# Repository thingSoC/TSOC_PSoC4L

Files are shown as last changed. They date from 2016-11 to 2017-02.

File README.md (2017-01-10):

# TSOC_PSoC4L - PSoC4 (Large) Embedded Module :

The TSOC_PSoC4L is a [PSoC4-Programmable System on Chip](http://www.cypress.com/documentation/datasheets/psoc-4-psoc-4200l-family-datasheet)
based board with integrated USB and Li-Po battery power and charging functions, 
in an Embedded Module format for the new thingSoC, Internet of Things open standard.

The TSOC_PSoC4L is a low cost, embeddable module featuring a PSoC4 "Large" device :

* 32-bit MCU Subsystem (48MHZ ARM Cortex-M0)
* USB Full-Speed Controller - 16 Endpoints
* Li-Po battery connector and integrated USB charger
* Programmable Analog Blocks (4 blocks)
* Programmable Digital Blocks (8 blocks)
* 3.3 Volt or 5.0 Volt Operation
* Serial Communication (3 Ports)
* Counter/Timers/PWMs (8 Ports)
* CAN (controller area network) Controller
* Battery Charge Status LED
* USER LED
* USER Pushbutton
* Optional 32Khz Oscillator for Real-Time Clock
* Optional High Precision Oscillator
* Optional FM24W256-G NVSRAM (32K Bytes Nonvolatile SRAM)
* [thingSoC Compliant Module](http://www.thingsoc.com)
* [Mikrobus Compatible Module](http://www.mikroe.com/mikrobus/) 

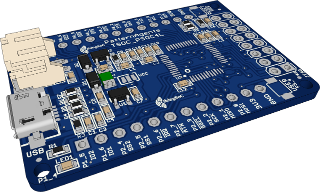
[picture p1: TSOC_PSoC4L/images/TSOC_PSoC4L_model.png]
thingSoC TSOC_PSoC4L
[TSOC_PSoC4L](https://github.com/thingSoC/TSOC_PSoC4L)

**thingSoC Reference Designs** are example thingSoC implementations that implement
various reference and testing circuits for demonstrating the use of the thingSoC libraries.
These reference designs can serve as starting templates for user designs.

---------------------------------------

## TSOC_PSoC4L Instructions

The TSOC_PSoC4L comes preprogrammed with a command line interpreter (CLI)
that runs on the enumerated USB COM port by default. It can be changed to
run onother ports interactively.

Immediately after plugging in the USB or Li-Po battery power the TSOC_PSoC4L will :

1) Runs a USB bootloader for ten (10) seconds to allow you to update the firmware.
   Use the [Cypress Bootloader Host](http://www.cypress.com/documentation/application-notes/an68272-psoc-3-psoc-4-psoc-5lp-and-psoc-analog-coprocessor-uart)
   to load new firmware into the device to customize it.

2) Runs the RSVP command line interpreter with the following commands :
  * commands : display the list of currenyl available commands
  * info : display the firmware revision number and other board details
  * echo : echo the current command
  * test adc : display all current ADC channel values
  * test uart : sends test string to all UART ports
  * test boot : run the bootloader
  * console x : changes the console to port "X"
  * connect x y : connect port x to port y until the user button is pressed to exit  
    where :  X (Y) = 
    0 - USB Port
    1 - UART1 Port
    2 - UART2 Port
    3 - I2C1 Port
    4 - I2C2 Port
    5 - SPI1 Port
    6 - SPI2 Port

---------------------------------------
## Other Applications

The TSOC_PSoC4L can also drive other devices, such as Servos, Motors, Relays and more.
This requires custom firmware at the current time.

---------------------------------------

## TSOC_PSoC4L Status <a name="TSOC_PSoC4L_status"/>

**11/06/2016:** 
Revision 1.0 - Initial Layout released to OSHpark

---------------------------------------
## TSOC_PSoC4L Model Images

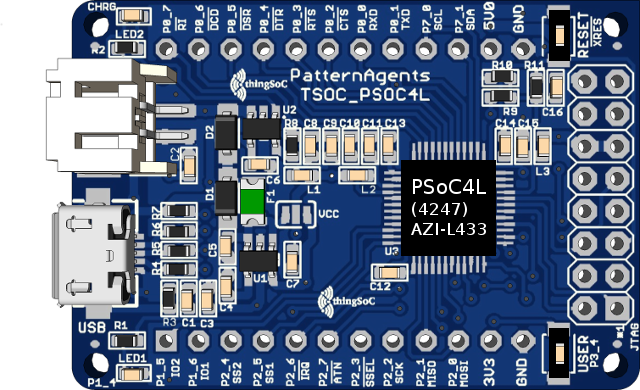
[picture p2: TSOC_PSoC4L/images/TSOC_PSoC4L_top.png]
thingSoC TSOC_PSoC4L
[TSOC_PSoC4L](https://github.com/thingSoC/TSOC_PSoC4L)

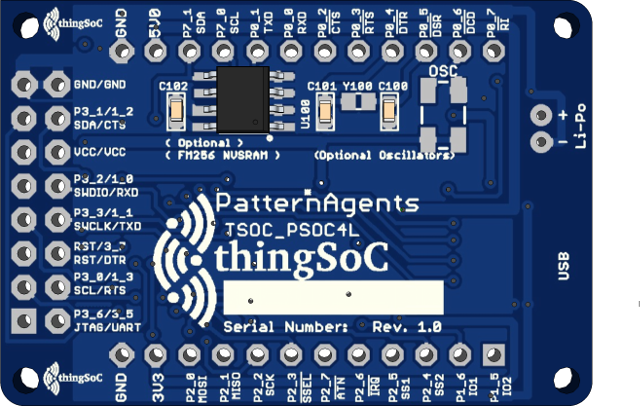
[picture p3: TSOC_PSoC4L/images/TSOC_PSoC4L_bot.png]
thingSoC TSOC_PSoC4L
[TSOC_PSoC4L](https://github.com/thingSoC/TSOC_PSoC4L)

---------------------------------------

## TSOC_PSoC4L Documentation Index <a name="TSOC_PSoC4L_documentation_index"/>

[TSOC_PSoC4L Project](http://thingsoc.github.io/projects/TSOC_PSoC4L.html)

[TSOC_PSoC4L Hardware](https://github.com/thingSoC/TSOC_PSoC4L/tree/master/TSOC_PSoC4L/hardware)

---------------------------------------

## thingSoC Documentation Index <a name="thingSoC_documentation_index"/>

[thingSoC Organization Website](http://thingSoC.github.io)

[thingSoC FAQ - Frequently Asked Questions](http://thingsoc.github.io/support/faq.html)

---------------------------------------

[thingSoC 
*thingSoC*](http://thingsoc.github.io)

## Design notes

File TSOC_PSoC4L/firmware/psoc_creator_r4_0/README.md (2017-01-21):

# TSOC_PSoC4L - PSOC Creator Firmware :

Note Bene : These project firmware bundles require PSOC Creator Version 4.0 or later.

Firmware Source and Images for the TSOC_PSoC4L board.

1) rsvpsis_4l_typ.R1_3_1.zip : First Release bundle.

   USB/HID Bootloader (10 seconds after reset)

   USB/CDC ComX: Interface (after bootloader exits)

   rsvpsis Command Line Interface - basic test functions

   "test" functions UART, ADC, LED, CrossConnect

The TSOC_PSoC4L is a [PSoC4-Programmable System on Chip](http://www.cypress.com/documentation/datasheets/psoc-4-psoc-4200l-family-datasheet)
based board with integrated USB and Li-Po battery power and charging functions, 
in an Embedded Module format for the new thingSoC, Internet of Things open standard.

---------------------------------------

## TSOC_PSoC4L Documentation Index <a name="TSOC_PSoC4L_documentation_index"/>

[TSOC_PSoC4L Project](http://thingsoc.github.io/projects/TSOC_PSoC4L.html)

[TSOC_PSoC4L Hardware](https://github.com/thingSoC/TSOC_PSoC4L/tree/master/TSOC_PSoC4L/hardware)

---------------------------------------

## thingSoC Documentation Index <a name="thingSoC_documentation_index"/>

[thingSoC Organization Website](http://thingSoC.github.io)

[thingSoC FAQ - Frequently Asked Questions](http://thingsoc.github.io/support/faq.html)

---------------------------------------

[thingSoC 
*thingSoC*](http://thingsoc.github.io)

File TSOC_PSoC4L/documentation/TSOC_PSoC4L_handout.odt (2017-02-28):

thingSoC PSoC4L Board

Thank you for purchasing a TSOC_PSoC4L board!
Please see the Getting Started Guide at :
https://github.com/thingSoC/TSOC_PSoC4L (https://github.com/thingSoC/TSOC_NEOLED)
It has complete instructions and examples to download.

thingSoC PSoC4L Board

Thank you for purchasing a TSOC_PSoC4L board!
Please see the Getting Started Guide at :
https://github.com/thingSoC/TSOC_PSoC4L (https://github.com/thingSoC/TSOC_NEOLED)
It has complete instructions and examples to download.

thingSoC PSoC4L Board

Thank you for purchasing a TSOC_PSoC4L board!
Please see the Getting Started Guide at :
https://github.com/thingSoC/TSOC_PSoC4L (https://github.com/thingSoC/TSOC_NEOLED)
It has complete instructions and examples to download.

thingSoC PSoC4L Board

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

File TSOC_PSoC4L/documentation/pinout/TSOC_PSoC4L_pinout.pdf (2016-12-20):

Sheet1

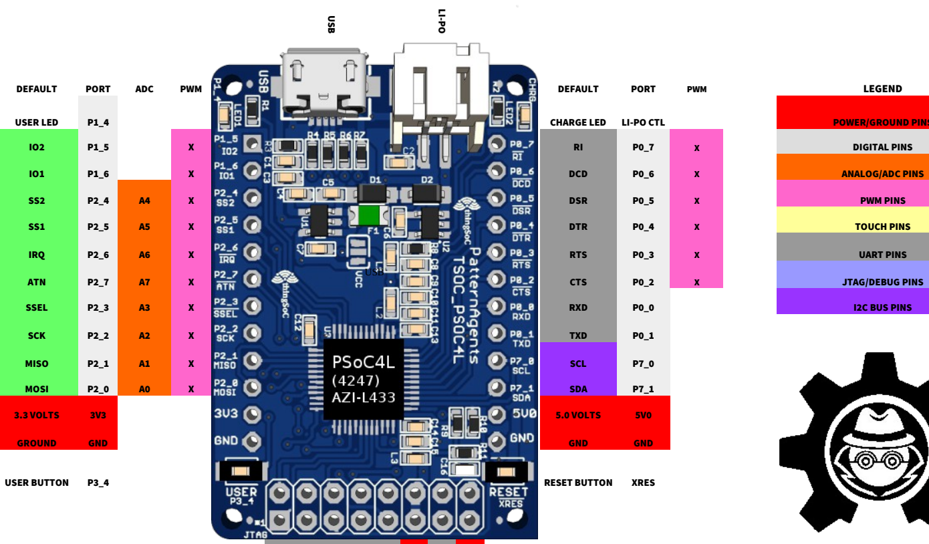
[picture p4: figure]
USB; DIGITAL PINS; DCD; ANALOG/ADC PINS; DSR; PWM PINS; DTR; TOUCH PINS; IRQ; RTS; UART PINS; SSEL; RXD; I2C BUS PINS; SCK; TXD; MISO; SCL; MOSI; SDA; 3.3 VOLTS; 5.0 VOLTS; GROUND; GND; USER BUTTON; RESET BUTTON; XRES

Page 1

DEFAULT | PORT | ADC | PWM | DEFAULT | PORT | PWM | LEGEND
USER LED | P1_4 | | | CHARGE LED | LI-PO CTL | | POWER/GROUND PINS
ATN | P2_7 | A7 | X | CTS | P0_2 | X | JTAG/DEBUG PINS

DSR1 (P3_5)
RTS1 (P1_3)

DTR1 (P3_7)
TXD1 (P1_1)

RXD1 (P1_0)

5V0

CTS1 (P1_2)

GND

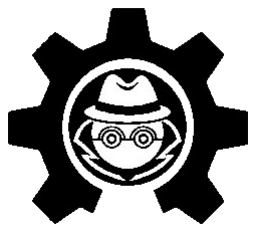
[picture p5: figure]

## PatternAgents TSOC_PSoC4L Board

DEBUG (P3_6)
SCL1 (P3_0)
RESET#

SWDCLK (P3_3)
SWDIO (P3_2)

VCC

SDA1 (P3_1)

GND

## thingsoc/TSOC_PSoC4L/ (http://github.com/thingsoc/TSOC_PSoC4L/)

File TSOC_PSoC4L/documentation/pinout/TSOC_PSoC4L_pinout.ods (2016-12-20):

 |  |  |  |  |  | USB |  |  |  | LI-PO
DEFAULT | PORT | ADC | PWM |  |  |  |  |  |  |  |  | DEFAULT | PORT | PWM | LEGEND
USER LED | P1_4 |  |  |  |  |  |  |  |  |  |  | CHARGE LED | LI-PO CTL |  | POWER/GROUND PINS
IO2 | P1_5 |  | X |  |  |  |  |  |  |  |  | RI | P0_7 | X | DIGITAL PINS
IO1 | P1_6 |  | X |  |  |  |  |  |  |  |  | DCD | P0_6 | X | ANALOG/ADC PINS
SS2 | P2_4 | A4 | X |  |  |  |  |  |  |  |  | DSR | P0_5 | X | PWM PINS
SS1 | P2_5 | A5 | X |  |  |  |  |  |  |  |  | DTR | P0_4 | X | TOUCH PINS
IRQ | P2_6 | A6 | X |  |  |  |  |  |  |  |  | RTS | P0_3 | X | UART PINS
ATN | P2_7 | A7 | X |  |  |  |  |  |  |  |  | CTS | P0_2 | X | JTAG/DEBUG PINS
SSEL | P2_3 | A3 | X |  |  |  |  |  |  |  |  | RXD | P0_0 |  | I2C BUS PINS
SCK | P2_2 | A2 | X |  |  |  |  |  |  |  |  | TXD | P0_1 |  | SPI BUS PINS
MISO | P2_1 | A1 | X |  |  |  |  |  |  |  |  | SCL | P7_0
MOSI | P2_0 | A0 | X |  |  |  |  |  |  |  |  | SDA | P7_1
3.3 VOLTS | 3V3 |  |  |  |  |  |  |  |  |  |  | 5.0 VOLTS | 5V0
GROUND | GND |  |  |  |  |  |  |  |  |  |  | GND | GND
USER BUTTON | P3_4 |  |  |  |  |  |  |  |  |  |  | RESET BUTTON | XRES
 |  |  |  | DSR1 (P3_5) | RTS1 (P1_3) | DTR1 (P3_7) | TXD1 (P1_1) | RXD1 (P1_0) | 5V0 | CTS1 (P1_2) | GND |  |  | PatternAgents TSOC_PSoC4L Board
 |  |  |  | DEBUG (P3_6) | SCL1 (P3_0) | RESET# | SWDCLK (P3_3) | SWDIO (P3_2) | VCC | SDA1 (P3_1) | GND |  | thingsoc/TSOC_PSoC4L/ (http://github.com/thingsoc/TSOC_PSoC4L/)

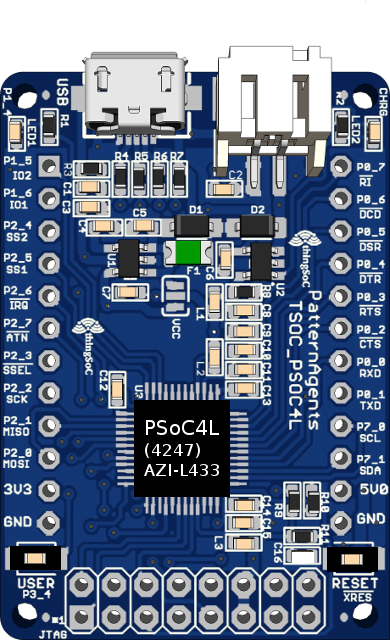
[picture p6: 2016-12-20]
TSOC_PSoC4L/images/TSOC_PSoC4L_pinout.png

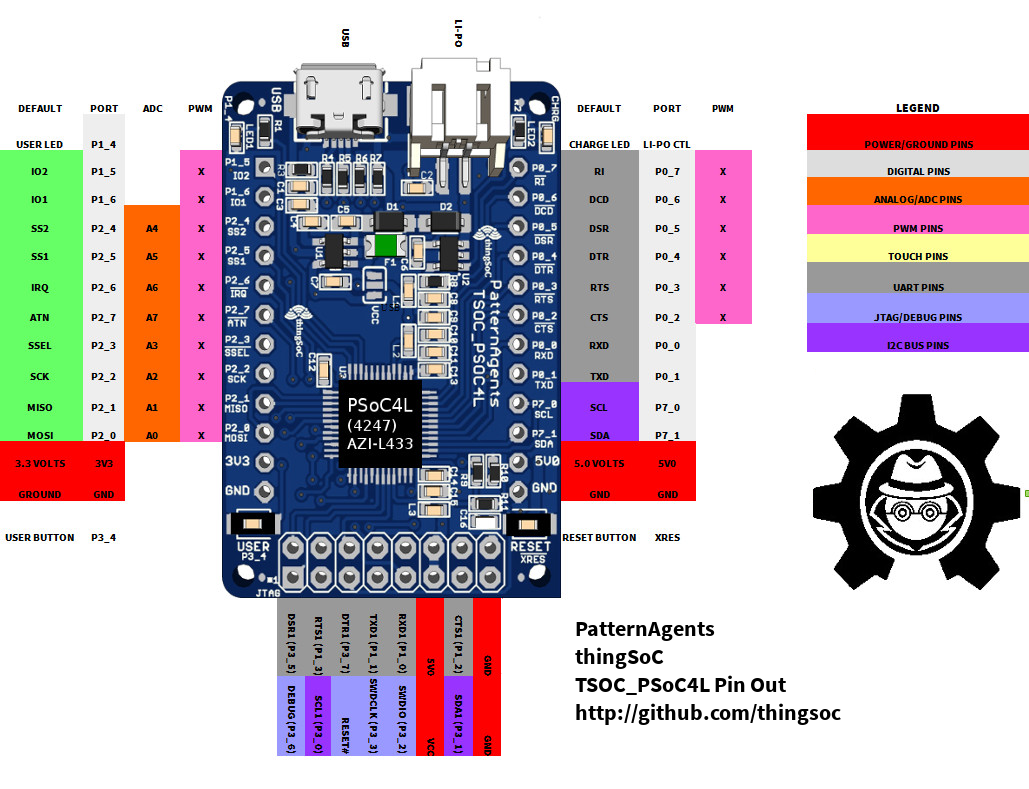
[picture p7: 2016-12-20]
TSOC_PSoC4L/documentation/pinout/TSOC_PSoC4L_pinout.png

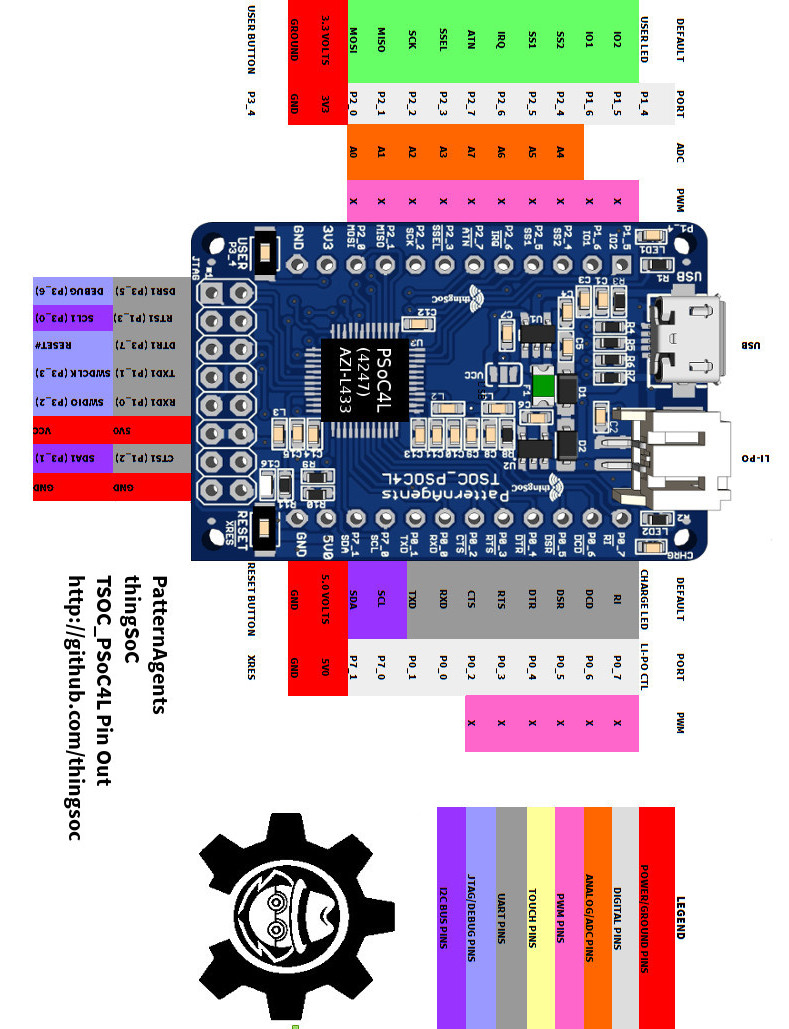
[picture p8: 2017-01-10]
TSOC_PSoC4L/documentation/pinout/TSOC_PSoC4L_pinout_long.jpg

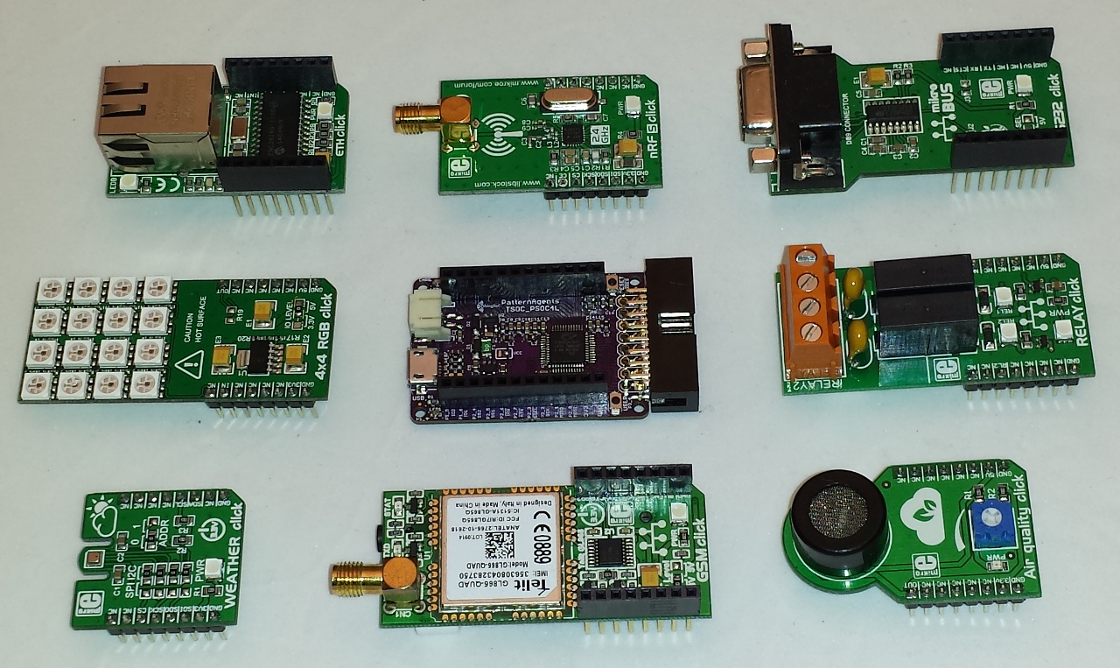
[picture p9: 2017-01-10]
TSOC_PSoC4L/images/product/TSOC_PSoC4L_Clicks.jpg

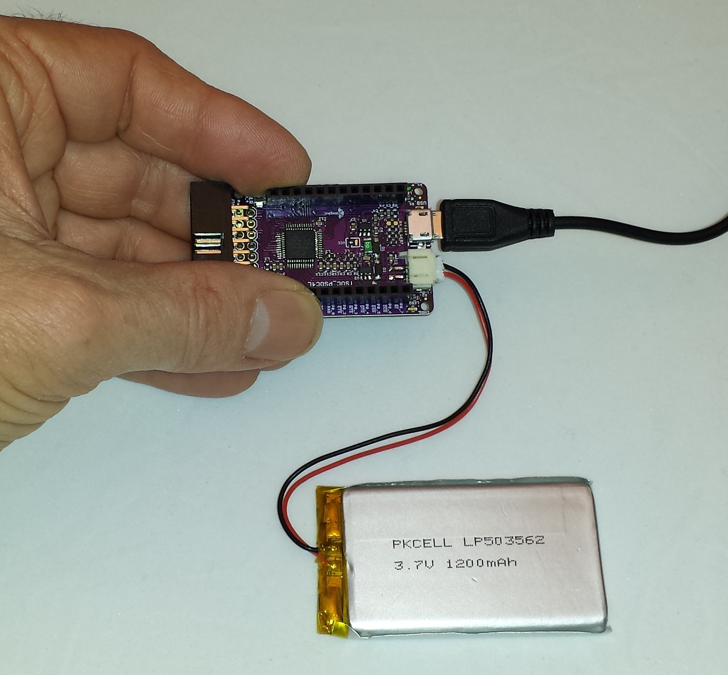
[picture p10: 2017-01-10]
TSOC_PSoC4L/images/product/TSOC_PSoC4L_USB_LiPo.jpg

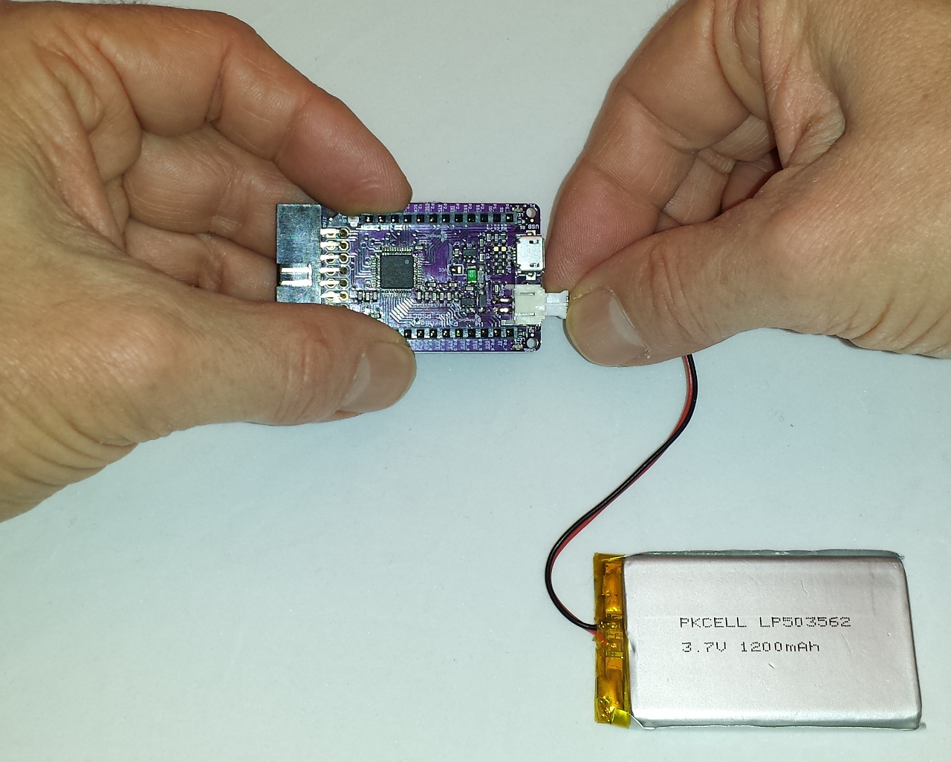
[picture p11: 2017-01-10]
TSOC_PSoC4L/images/product/TSOC_PSoC4L_LiPo1.jpg

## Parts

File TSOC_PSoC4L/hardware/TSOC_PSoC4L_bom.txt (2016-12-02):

Partlist exported from U:/PatternAgents/eagle/TSOC_Modules/TSOC_PSoC4L/TSOC_PSoC4L/revisions/REV1_0/TSOC_PSoC4L.sch at 11/17/2016 4:03:40 PM

Qty Value             Device                                                Package                   Parts                           Description                                                                                                   
1                     JST_2MM_MALE                                          JST-2-SMD                 BATTERY                         Mates to single-cell LiPo batteries.                                                                          
1                     M02-JST-2-PTH-NO_SILK                                 JST-2-PTH-NS              J1P                             Standard 2-pin 0.1" header. Use with                                                                          
1                     M08X2                                                 2X8                       JTAG                            .1" headers, two rows of 8 each                                                                               
7   100nf             CERAMIC-100NF-50V-10%-X7R(0603)                       C0603                     C1, C4, C8, C11, C14, C16, C102 302010138                                                                                                     
4   10K 1/10W         SMD-RES-10K-5%-1/10W(0603)                            R0603                     R8, R9, R10, R11                301010293                                                                                                     
3   10uf              CERAMIC-10UF-10V-10%-X5R(0603)                        C0603                     C3, C5, C7                      302010103                                                                                                     
2   12pf              CERAMIC-12PF-50V-5%-NPO(0603)                         C0603                     C100, C101                      302010067                                                                                                     
2   1K 1/10W          SMD-RES-1K-5%-1/10W(0603)                             R0603                     R1, R2                          301010291 
2   0 1/10W           SMD-RES-0-5%-1/10W(0603)                              R0603                     R7 
1   1M 1/10W          SMD-RES-1M-5%-1/10W(0603)                             R0603                     R3                              301010100                                                                                                     
7   1uf               CERAMIC-1UF-25V-10%-X7R(0603)                         C0603                     C2, C6, C9, C10, C12, C13, C15  302010139                                                                                                     
2   20V-1A            SMD-DIODE-SCHOTTKY-20V-1A(SOD-123)                    SOD-123                   D1, D2                          304020034                                                                                                     
2   22R               SMD-RES-22R-5%-1/10W(0603)                            R0603                     R5, R6                          301010289                                                                                                     
1   3.2768KHZ         SMD-CRYSTAL-32.768KHZ-12.5PF-20PPM-90K(2P-L2.0X1.2MM) X2-SMD-L2.0X1.2X0.55MM    Y100                            306010020                                                                                                     
3   330OHM-500MA      SMD-FERRITE-CHIP-120-OHM-500MA(0603)                  L0603                     L1, L2, L3                      303030001                                                                                                     
1   500mA-PTC         PTCSMD                                                PTC-1206                  F1                              Resettable Fuse PTC                                                                                           
1   AP2112K-3.3V      V_REG_LDOSMD                                          SOT23-5                   U1                              Voltage Regulator LDO                                                                                         
2   B3U-1000P-2P-SMD  SMD-BUTTON(2P-3.0X2.5X1.2+0.4MM)-B3U-1000P-2P-SMD     SW2-2.6-3.0X2.5X1.2+0.4MM RESET, USER                     311020047                                                                                                     
1   CY8C4247AZI-L433  CY8C4247AZI-L433                                      TQFP-7X7-48               U3                              Cypress PSoC® 4 - Programmable System on Chip,  Cortex-M0 Based : USB Version!                                
1   DNP               SMD-RES-22R-5%-1/10W(0603)                            R0603                     R4                              301010289                                                                                                     
4   FIDUCIALUFIDUCIAL FIDUCIALUFIDUCIAL                                     MICRO-FIDUCIAL            FID1, FID2, FID3, FID4          Fiducial Alignment Points                                                                                     
1   FM24W256-G        FM24W256-G                                            SO08                      U100                            I2C FRAM FM24W256                                                                                             
1   GREEN-0603        SMD-LED-CLEAR-GREEN(0603)                             LED-0603                  LED1                            304090043                                                                                                     
1   JMP-3-1_2         JMP-3-1_2                                             JMP-3-1_2                 VCC                             Three Terminal Jumper - 1 & 2 Connected                                                                       
1   MCP73831          MCP73831                                              SOT23-5                   U2                              Miniature single cell, fully integrated Li-Ion, Li-polymer charge management controller                       
1   OSCILLATOR5X3     OSCILLATOR5X3                                         CRYSTAL-SMD-5X3           OSC                             Generic 5x3 and 7x5 oscillators                                                                               
1   USB_AB            USB_AB                                                USB-AB-MICRO-SMD          USB                             This is a USB AB connector that is compatible with USB OTG. i.e. this connector can serve as a host or device 
1   YELLOW-0603       SMD-LED-CLEAR-YELLOW(0603)                            LED-0603                  LED2                            304090044

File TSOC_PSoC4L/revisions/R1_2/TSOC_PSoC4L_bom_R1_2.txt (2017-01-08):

Partlist exported from U:/PatternAgents/eagle/TSOC_Modules/TSOC_PSoC4L/TSOC_PSoC4L/revisions/R1_2/TSOC_PSoC4L.sch at 12/18/2016 4:06:15 PM

Qty Value             Device                               Package           Parts                                 Description                                                                                                   
1   AP2112K-3.3V      V_REG_LDOSMD                         SOT23-5           U1                                    Voltage Regulator LDO                                                                                         
1   MCP73831          MCP73831                             SOT23-5           U2                                    Miniature single cell                     
1   CY8C4247AZI-L433  CY8C4247AZI-L433                     TQFP-7X7-48       U3                                    Cypress PSoC® 4 -                         
8   100nf             CERAMIC-100NF-50V-10%-X7R(0603)      C0603             C1, C8, C11, C14, C16, C102, C103     302010138                                                                                                     
3   10uf              CERAMIC-10UF-10V-10%-X5R(0603)       C0603             C3, C5, C7                            302010103                                                                                                     
7   1uf               CERAMIC-1UF-25V-10%-X7R(0603)        C0603             C2, C6, C9, C10, C12, C13, C15        302010139                                                                                                     
1   47uf              TANTALUM-SMD-47UF-6.3V(AVX-A)        AVX-A             C17                                   302020005                                                                                                     
2   1K 1/10W          SMD-RES-1K-5%-1/10W(0603)            R0603             R1, R2                                301010291                                                                                                     
1   1M 1/10W          SMD-RES-1M-5%-1/10W(0603)            R0603             R3                                    301010100                                                                                                     
2   22R               SMD-RES-22R-5%-1/10W(0603)           R0603             R5, R6                                301010289
4   10K 1/10W         SMD-RES-1M-5%-1/10W(0603)            R0603             R8, R9, R10, R11                                                                                               
3   330OHM-500MA      SMD-FERRITE-CHIP-120-OHM-500MA(0603) L0603             L1, L2, L3                            303030001                                                                                                     
2   20V-1A            SMD-DIODE-SCHOTTKY-20V-1A(SOD-123)   SOD-123           D1, D2                                304020034                                                                                                     
1   500mA-PTC         PTCSMD                               PTC-1206          F1                                    Resettable Fuse PTC                                                                                           
2   B3U-1000P-2P-SMD  SMD-BUTTON(2P-3.0X2.5X1.2+0.4MM      SW2               RESET, USER                           311020047                                                                                                     
1   GREEN-0603        SMD-LED-CLEAR-GREEN(0603)            LED-0603          LED1                                  304090043                                                                                                     
1   YELLOW-0603       SMD-LED-CLEAR-YELLOW(0603)           LED-0603          LED2                                  304090044                                                                                                     
1   JMP-3-1_2         JMP-3-1_2                            JMP-3-1_2         VCC                                   Three Terminal Jumper - 1 & 2 Connected                                                                       
1   USB_AB            USB_AB                               USB-AB-MICRO-SMD  USB                                   This is a USB AB 
1                     JST_2MM_MALE                         JST-2-SMD         BATTERY                               Mates to single-c                                                                        
1                     M02-JST-2-PTH-NO_SILK                JST-2-PTH-NS      J1P                                   Standard 2-pin                                                                        
1                     M08X2                                2X8               JTAG                                  .1" headers, two rows of 8 each                                                                               

Do Not Populate!
----------------
1   DNP               470pf                                C0603             C4
1   DNP               SMD-RES-22R-5%-1/10W(0603)           R0603             R4                                                                                                                                         
1   FM24W256-G        FM24W256-G                           SO08              U100                                  I2C FRAM FM24W256                                                                                             
2   12pf              CERAMIC-12PF-50V-5%-NPO(0603)        C0603             C100, C101                            302010067                                                                                                     
1   3.2768KHZ         SMD-CRYSTAL-32.768KHZ-12.5PF-20PPM   X2-SMD            Y100                                  306010020                                                                                                     
1   OSCILLATOR5X3     OSCILLATOR5X3                        CRYSTAL-SMD-5X3   Y101                                  Generic 5x3 and 7x5 oscillators

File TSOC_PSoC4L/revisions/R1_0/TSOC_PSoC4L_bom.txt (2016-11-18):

Partlist exported from U:/PatternAgents/eagle/TSOC_Modules/TSOC_PSoC4L/TSOC_PSoC4L/revisions/REV1_0/TSOC_PSoC4L.sch at 11/17/2016 4:03:40 PM

Qty Value             Device                                                Package                   Parts                           Description                                                                                                   
1                     JST_2MM_MALE                                          JST-2-SMD                 BATTERY                         Mates to single-cell LiPo batteries.                                                                          
1                     M02-JST-2-PTH-NO_SILK                                 JST-2-PTH-NS              J1P                             Standard 2-pin 0.1" header. Use with                                                                          
1                     M08X2                                                 2X8                       JTAG                            .1" headers, two rows of 8 each                                                                               
7   100nf             CERAMIC-100NF-50V-10%-X7R(0603)                       C0603                     C1, C4, C8, C11, C14, C16, C102 302010138                                                                                                     
4   10K 1/10W         SMD-RES-10K-5%-1/10W(0603)                            R0603                     R8, R9, R10, R11                301010293                                                                                                     
3   10uf              CERAMIC-10UF-10V-10%-X5R(0603)                        C0603                     C3, C5, C7                      302010103                                                                                                     
2   12pf              CERAMIC-12PF-50V-5%-NPO(0603)                         C0603                     C100, C101                      302010067                                                                                                     
3   1K 1/10W          SMD-RES-1K-5%-1/10W(0603)                             R0603                     R1, R2, R7                      301010291                                                                                                     
1   1M 1/10W          SMD-RES-1M-5%-1/10W(0603)                             R0603                     R3                              301010100                                                                                                     
7   1uf               CERAMIC-1UF-25V-10%-X7R(0603)                         C0603                     C2, C6, C9, C10, C12, C13, C15  302010139                                                                                                     
2   20V-1A            SMD-DIODE-SCHOTTKY-20V-1A(SOD-123)                    SOD-123                   D1, D2                          304020034                                                                                                     
2   22R               SMD-RES-22R-5%-1/10W(0603)                            R0603                     R5, R6                          301010289                                                                                                     
1   3.2768KHZ         SMD-CRYSTAL-32.768KHZ-12.5PF-20PPM-90K(2P-L2.0X1.2MM) X2-SMD-L2.0X1.2X0.55MM    Y100                            306010020                                                                                                     
3   330OHM-500MA      SMD-FERRITE-CHIP-120-OHM-500MA(0603)                  L0603                     L1, L2, L3                      303030001                                                                                                     
1   500mA-PTC         PTCSMD                                                PTC-1206                  F1                              Resettable Fuse PTC                                                                                           
1   AP2112K-3.3V      V_REG_LDOSMD                                          SOT23-5                   U1                              Voltage Regulator LDO                                                                                         
2   B3U-1000P-2P-SMD  SMD-BUTTON(2P-3.0X2.5X1.2+0.4MM)-B3U-1000P-2P-SMD     SW2-2.6-3.0X2.5X1.2+0.4MM RESET, USER                     311020047                                                                                                     
1   CY8C4247AZI-L433  CY8C4247AZI-L433                                      TQFP-7X7-48               U3                              Cypress PSoC® 4 - Programmable System on Chip,  Cortex-M0 Based : USB Version!                                
1   DNP               SMD-RES-22R-5%-1/10W(0603)                            R0603                     R4                              301010289                                                                                                     
4   FIDUCIALUFIDUCIAL FIDUCIALUFIDUCIAL                                     MICRO-FIDUCIAL            FID1, FID2, FID3, FID4          Fiducial Alignment Points                                                                                     
1   FM24W256-G        FM24W256-G                                            SO08                      U100                            I2C FRAM FM24W256                                                                                             
1   GREEN-0603        SMD-LED-CLEAR-GREEN(0603)                             LED-0603                  LED1                            304090043                                                                                                     
1   JMP-3-1_2         JMP-3-1_2                                             JMP-3-1_2                 VCC                             Three Terminal Jumper - 1 & 2 Connected                                                                       
1   MCP73831          MCP73831                                              SOT23-5                   U2                              Miniature single cell, fully integrated Li-Ion, Li-polymer charge management controller                       
1   OSCILLATOR5X3     OSCILLATOR5X3                                         CRYSTAL-SMD-5X3           OSC                             Generic 5x3 and 7x5 oscillators                                                                               
1   TSOC-24-BB        TSOC-24-BB                                            TSOC-BB-S24               A                               thingSoC Twenty-Four(24) Pin Socket                                                                           
1   TSOC-LOGO-LRG     TSOC-LOGO-LRG                                         TSOC-LOGO-LRG             U$100                           thingSoC Logo                                                                                                 
3   TSOC-LOGO-SMALL   TSOC-LOGO-SMALL                                       TSOC-LOGO-SML             $$U$1, $$U$2, U$101             thingSoC Logo                                                                                                 
1   TSOC-PCB-SINGLE   TSOC-PCB-SINGLE                                       TSOC-BB-BRD-DIM           U$1                             thingSoC PCB Outlines                                                                                         
1   USB_AB            USB_AB                                                USB-AB-MICRO-SMD          USB                             This is a USB AB connector that is compatible with USB OTG. i.e. this connector can serve as a host or device 
1   YELLOW-0603       SMD-LED-CLEAR-YELLOW(0603)                            LED-0603                  LED2                            304090044

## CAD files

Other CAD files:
TSOC_PSoC4L/eagleUp/TSOC_PSoC4L.skp

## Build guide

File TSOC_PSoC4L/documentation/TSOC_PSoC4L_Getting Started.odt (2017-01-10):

Welcome to the thingSoC® PsoC4L (Large)

The TSOC_PSoC4L is a PSoC4-Programmable System on Chip (http://www.cypress.com/documentation/datasheets/psoc-4-psoc-4200l-family-datasheet) based board with integrated USB ,
Li-Po battery power and charging functions, in an Embedded Module format for the new thingSoC, Internet of Things open source hardware standard.

Getting Started :

1) Using a USB-Micro cable, plug the PSoC4L board into your Windows, MAC, or Linux PC.

2) The USB drivers should be found automatically on most systems.
However if they are not, they can be downloaded from :
https://github.com/thingSoC/TSOC_PSoC4L/tree/master/TSOC_PSoC4L/drivers

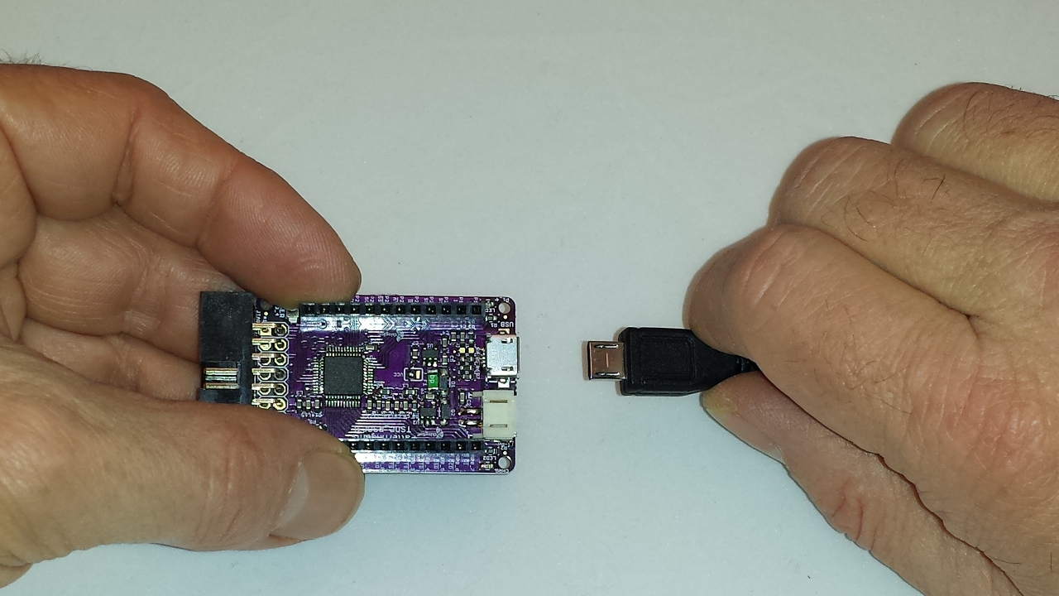
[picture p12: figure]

3) With the default firmware, when the PSoC4L board is first connected to power,
it will run the USB Bootloader program for the first ten (10) seconds of operation.
If a bootloader request to update the internal formware is not received within ten (10) seconds,
then the PSoC4L board will enter it's normal operating mode. In bootloader mode the PSoC4L
board enumerates as a USB HID (Human Interface Device) class device.

4) In normal operating mode (after ten seconds) the USER LED (Green) will blink at a one (1) second
blink rate; this indicates that the PSoC4L board is running the RSVP command line interpreter.
In normal operating mode, the PSoC4L board will enumerate as a USB CDC
(Communications Device Class) and appear to the computer as "COM" port.

5) Open a terminal program, like HyperTerm or TeraTerm, and connect to the COM: port that
enumerated when the PSoC4L board was plugged in, the baud rate setting doesn't matter as
it is a USB device.

6) Type "commands" and ENTER (carriage return) to get a listing of the RSVP commands.
See the appendix for a listing RSVP commands.

Lithium Battery Operation :
The TSOC_PSoC4L board includes a standard JST two(2) pin connector for commonly
available 3.7 volt, single cell, Lithium-Ion (Li-Po)batteries. Simply plug in the battery to power
the TSOC_PSoC4L as shown :


Lithium Battery Charging :
The TSOC_PSoC4L board includes a 3.7 volt, single cell, Lithium-Ion (Li-Po)battery charging circuit that is automatically enabled if USB power is connected, as shown :


The Yellow "CHRG" (Charge) LED will illuminate if the battery is charging, and it will shut off automatically once the battery is fully charged.

Safe Handling Precautions :

1) Always remove/unplug all power before inserting or removing peripherals.
2) Always ground yourself by touching a ground point before handling your boards.
3) Use a static safe bag when transporting your TSOC_PSoC4L board.

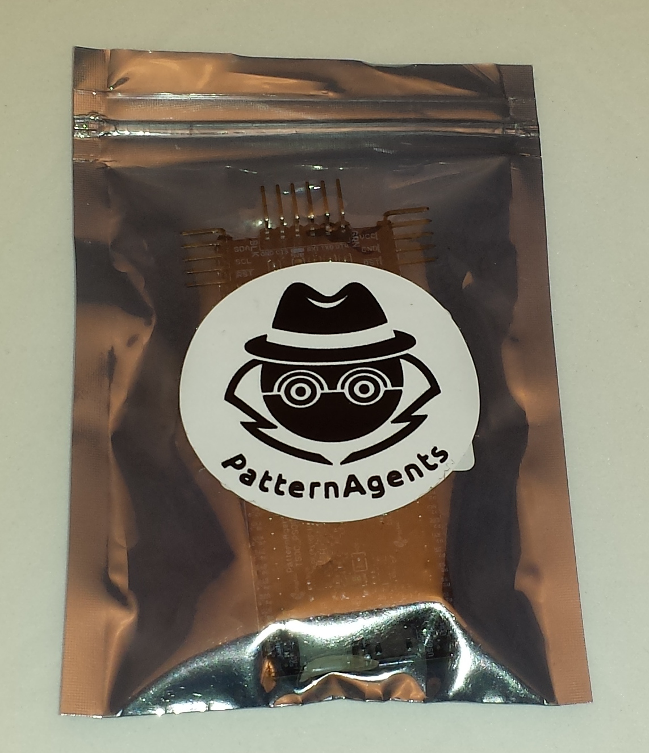
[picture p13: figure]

Adding Peripherals :
The TSOC_PSoC4L board supports both thingSoC and Mikrobus peripherals.
1) Make sure to align the SQUARE/CUT edges of the boards together to insure that
the polarity is correct. Push down evenly to seat the boards in the socket.
2) Note that the "stacking pins" are somewhat longer by design, and there will be some
extra space between the boards when using stacking connectors.


Reprogramming the TSOC_PsoC4L Board :

The TSOC_PSoC4L board comes pre-loaded with a USB-HID bootloader, which executes
for the first ten (10) seconds after powering up the board; either using USB or battery power.
This means that no additional programming dongles or hardware are needed to reprogram your board. You can also start the USB HID bootloader using the "test boot" command from the CLI.

The TSOC_PSoC4L board can be programmed using the Cypress PSoC Creator IDE,
which is a free download (registration required) from Cypress Semiconductor, and can be
found at :

http://www.cypress.com/products/psoc-creator-integrated-design-environment-ide

Cypress has a number of excellent videos and instructions online for using Creator.

The TSOC_PSoC4L board can also be programmed using the Cypress PSoC Programmer tool.
The PSoC Programmer tool is a free download (registration required) from Cypress Semiconductor,
and can be found at :

http://www.cypress.com/documentation/software-and-drivers/psoc-programmer-3245

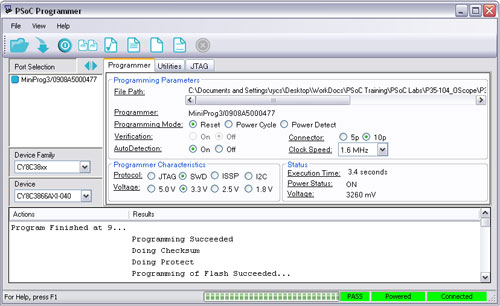
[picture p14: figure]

For more information, consult Cypress Semiconductor Application Note AN73503 : http://www.cypress.com/documentation/application-notes/an73503-psoc-usb-hid-bootloader
"Bare Metal" Programming :

At the factory we use a Cypress MiniProg3 JTAG programmer to install the default firmware on your TSOC_PSoC4L board before it ships to you. If you would like to do bare metal programming or to use the PSoC Creator debugger, you will need a MiniProg3 and a MiniProg adapter.
You can find more information about the MiniProg3 here :
http://www.cypress.com/documentation/development-kitsboards/cy8ckit-002-psoc-miniprog3-program-and-debug-kit

thingSoC MiniProg Adapter :

The thingSoC MiniProg adapter is used to provide several interfaces through a single common
connector on the TSOC_PSoC4L board, including JTAG, UART, and I2C as shown :

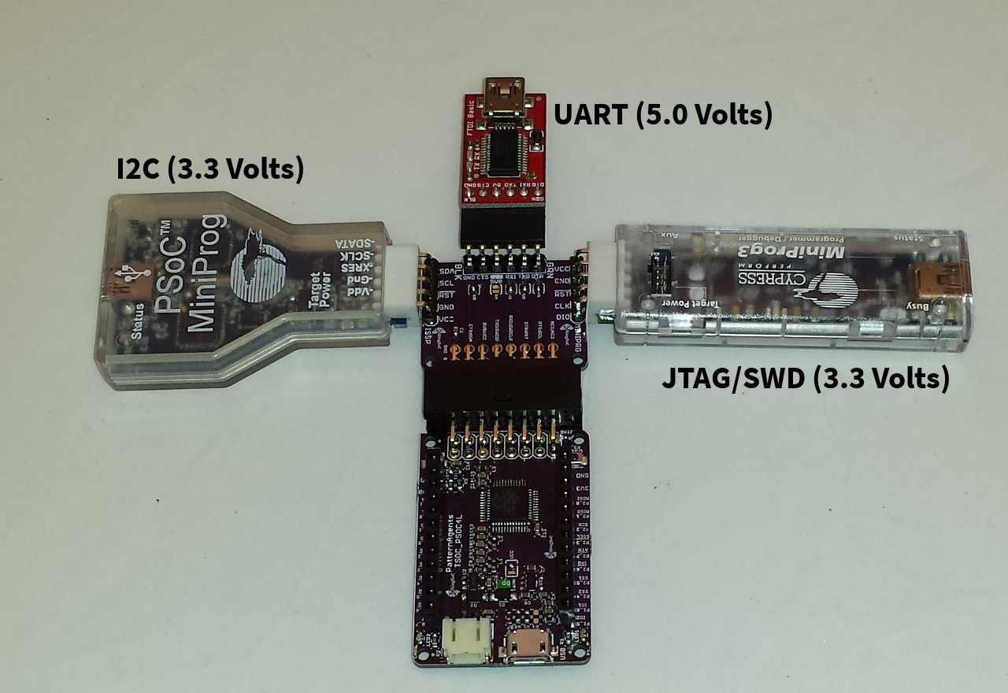
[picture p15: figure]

The thingSoC MiniProg adapter implements the thingSoC DPC (Digital Programming Connector) and allows for programming, testing, and debugging using either a UART or I2C bootloader, or bare metal programming using JTAG/SWD. This is generally for advanced users only, and is not normally required for User programming. Most Users wll simply use the USB interface for reprogramming.
Note that the USB-UART (FTDI) is a 5.0 Volt ONLY connection for backward compatibility.
thingSoC PsoC4L Optional Hardware :

The TSOC_PsoC4L has footprints on the reverse side of the board that are not populated by default.
These include options for a Real-Time Clock Watch Crystal (32Khz) , a second Oscillator (5x3mm), and a socket for a Cypress NVSRAM component, as shown below :

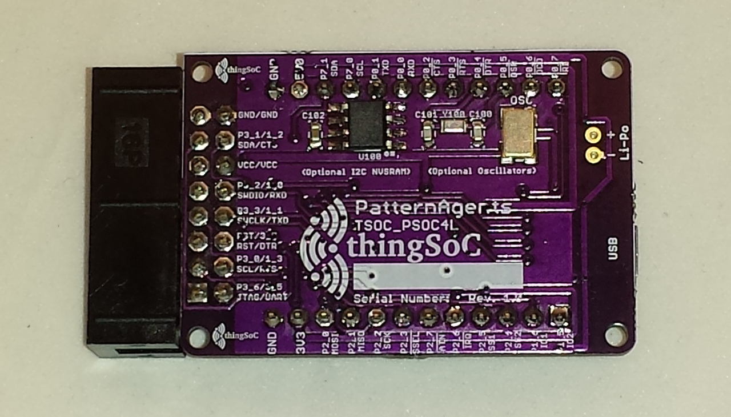
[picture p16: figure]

Complete documention, including schematics, layouts, gerbers, and Bill of Materials (BOM) are available on the thingSoC website at :

https://github.com/thingSoC/TSOC_PSoC4L/tree/master/TSOC_PSoC4L

There is also a project Wiki available for asking questions and more information at :

https://github.com/thingSoC/TSOC_PSoC4L/wiki

thingSoC RSVP Command Summary :

The default firmware includes the RSVP command line interpreter, which can be accessed using
any terminal emulator program (HyperTerm, TeraTerm, CuteTerm, etc.) on the USB COM: port that enumerates after the USB HID bootloader exits.

commands <CR> Display a list of the currently available commands

info <CR> Display the current firmware revision

echo <CR> Display the current command parameters

console X <CR> Move the CLI console to port X
(change the console port to a Wireless radio, for example)

connect X Y <CR> Connect Port X to Port Y (until USER Switch is pressed)
(useful for testing Radios, and serial peripherals)

test adc <CR> Display the current ADC readings for all ADC channels

test boot <CR> Enter the bootloader program to update the firmware

test led <CR> Blink all onboard LEDs

X = 0 = USB Port
X = 1 = UART1
X = 2 = UART2
X = 3 = I2C1
X = 4 = I2C2
X = 5 = SPI1
X = 6 = SPI2

(for Firmware version 1.3.0 – more commands are being added...)

thingSoC FRU (Field Replaceable Unit) Summary :

The second I2C unit (I2C2) is programmed using EZ-I2C to act as an emulated EEPROM,
containing a standard IPMI (Intelligent Peripheral Management Interface) record for a
FRU (Field Replaceable Unit). This data structure is used to contain information about
the board serial number, date and location of manufacturing, asset number, etc.

For more information, please see the IPMI FRU Specification at :

http://www.intel.com/content/dam/www/public/us/en/documents/product-briefs/platform-management-fru-document-rev-1-2-feb-2013.pdf

thingSoC® PSoC4L Features :

The TSOC_PSoC4L is a low cost, embeddable module featuring a PSoC4 "Large" device :

- 32-bit MCU Subsystem (48MHZ ARM Cortex-M0)
- USB Full-Speed Controller - 16 Endpoints
- Li-Po battery connector and integrated USB charger
- Programmable Analog Blocks (4 blocks)
- Programmable Digital Blocks (8 blocks)
- 3.3 Volt or 5.0 Volt Operation
- Serial Communication (3 Ports)
- Counter/Timers/PWMs (8 Ports)
- CAN (controller area network) Controller
- Battery Charge Status LED
- USER LED
- USER Pushbutton
- Optional 32Khz Oscillator for Real-Time Clock
- Optional High Precision Oscillator (High accuracy CAN/Baud rate clock)
- Optional FM24W256-G NVSRAM (32K Bytes Nonvolatile SRAM)
- thingSoC Compliant Module
- Mikrobus Compatible Module (http://www.mikroe.com/mikrobus/)


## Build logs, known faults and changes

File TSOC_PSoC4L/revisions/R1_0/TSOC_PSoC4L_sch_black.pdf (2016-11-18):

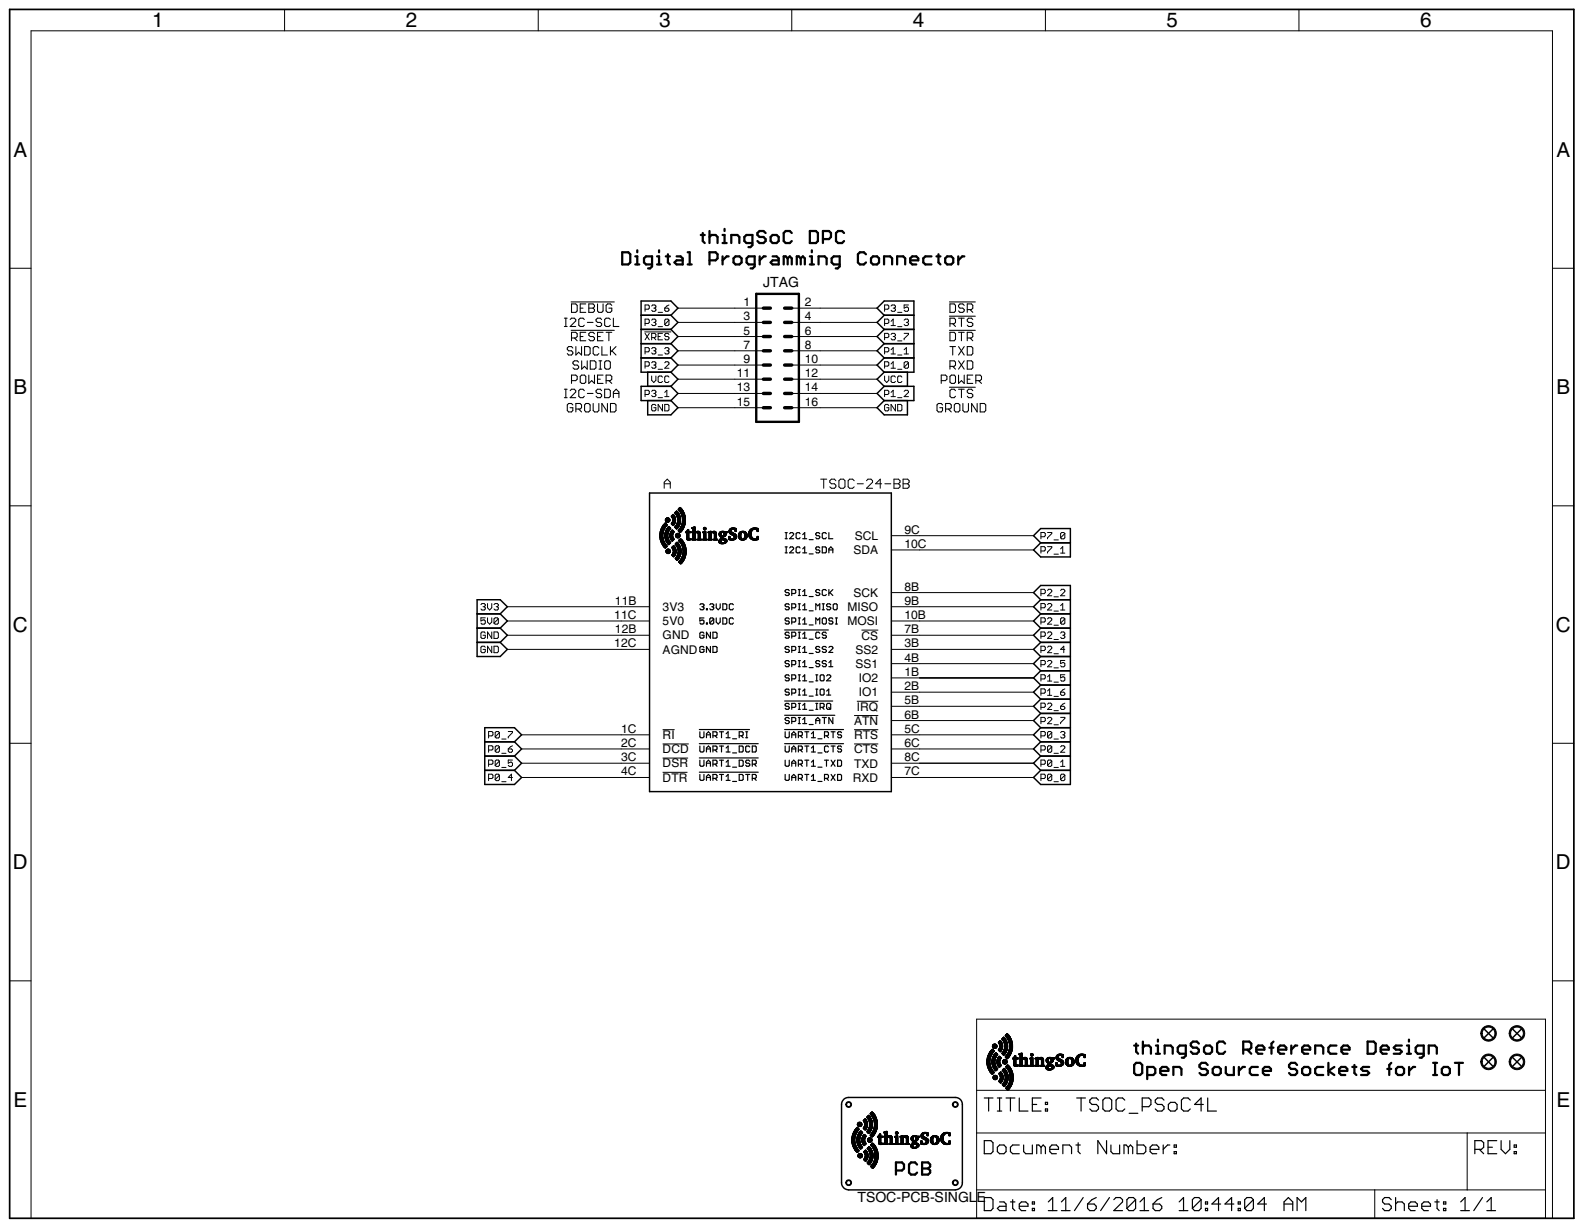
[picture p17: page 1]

100nf 1uf 100nf 1uf 1uf GND GND GND 10K 1/10W 100nf 1uf GND 1K 1/10W 10K 1/10W 10K 1/10W 1uf GNDGND 500mA-PTC GND GND 100nf 1M 1/10W GND GND GND GND 10uf GND GND GND 100nf GND 20V-1A MCP73831 GND GND GND 10K 1/10W 1K 1/10W GND 330OHM-500MA 330OHM-500MA 330OHM-500MA 1uf 20V-1A AP2112K-3.3V 10uf YELLOW-0603 GREEN-0603 GND1uf 22R 22R DNP 100nf GND10uf TSOC-PCB-SINGLE B3U-1000P-2P-SMD B3U-1000P-2P-SMD 1K 1/10W GND 3.2768KHZ 12pf 12pf GND GND OSCILLATOR5X3 GND FM24W256-G 100nf GND GND C8C9 C11 C10 C13 R11 C14 C15 R1 R10 R9 C12 F1 D+D- VBUS GND USBID SHIELD1 SHIELD2 C1R3 C5 P2_0 2 P2_1 3 P2_3 5 P2_4 6 P2_5 7 P2_7 9 VSSD 10 P3_0 12 P3_1 13 P3_2_SWD 14 P3_3_SWC 16 P3_4 17 P3_5 18 P3_7 20 VDDIO 21 P4_0 22 USBDP_P13_0 23 USBDN_P13_1 24 P7_0 26 P0_0 28 P0_1 29 P0_3 31 P0_4 32 P0_5 33 P0_7 35 XRES 36 VCCD 37 VSSD 38 VDDD 39 VSSA 41 P1_0 42 P1_1 43 P1_3 45 P1_4 46 P1_5 47 P1_6 48 P1_7/VREF 1 P2_2 4 P2_6 8 P3_6 19 P0_6 34 P1_2 44 P0_2 30 NC 11 NC 15 VBUS 25 P7_1 27 VDDA 40 C16 D2 U2 VIN 4 STAT 1 VBAT 3 PROG 5 VSS 2 BATTERY R8 J1P 12 R2 L3L2L1 C6 ATN 6B RI 1C DCD 2C DSR 3C DTR 4C TXD 8C IO2 1B IO1 2B RTS 5C CTS 6C IRQ 5B SS2 3B SS1 4B CS 7B MOSI 10B MISO 9B SCK 8B GND 12B AGND 12C 3V3 11B RXD 7C SDA 10C SCL 9C 5V0 11C D1 U1INGNDOUT EN BP C3 LED2 LED1 C2 R5R6R4 C4 C7 JTAG 1 2 3 4 5 6 7 8 9 10 11 12 13 14 15 16 VCC 1 1 2 2 RESET 1 1 2 2 USER R7 Y100 C101 C100 OSCEN GND VCC OUT VSS 4 WP 7 VCC 8 SCL 6 SDA 5 A2 3 A0 1 A1 2 U100 C102 GND GND GND P1_2 P1_7 P1_6 P1_5 P1_4 P1_3 P1_1 P1_0 P2_0 P2_1 P2_2 P2_3 P2_4 P2_5 P2_6 P2_7 P3_0 P3_1 P3_2 P3_3 P3_4 P3_5 P3_6 P3_7 P4_0 P4_0 P0_0 P0_1 P0_2 P0_3 P0_4 P0_5 P0_6 P0_7 XRES VCCD VCCD 5V0 USB1_DM USB1_DM USB1_DP USB1_DP P7_1 P7_0 VDDIO VDDIO VDDA VDDA VDDD VDDD ABCDE ABCDE 1 2 3 4 5 6 ABCDE ABCDE 1 2 3 4 5 6 ABCDE ABCDE 1 2 3 4 5 6 ABCDE ABCDE 1 2 3 4 5 6 USB-AB GND GND GND GND GND GND Internal/Core Bypass Digital Bypass VDDIO Bypass SAR Bypass USB "B" Device Reset Pullup Heartbeat LED Analog Bypass I2C Pullups Switches 32,768 KHz Crystal (WCO/RTC Clock)

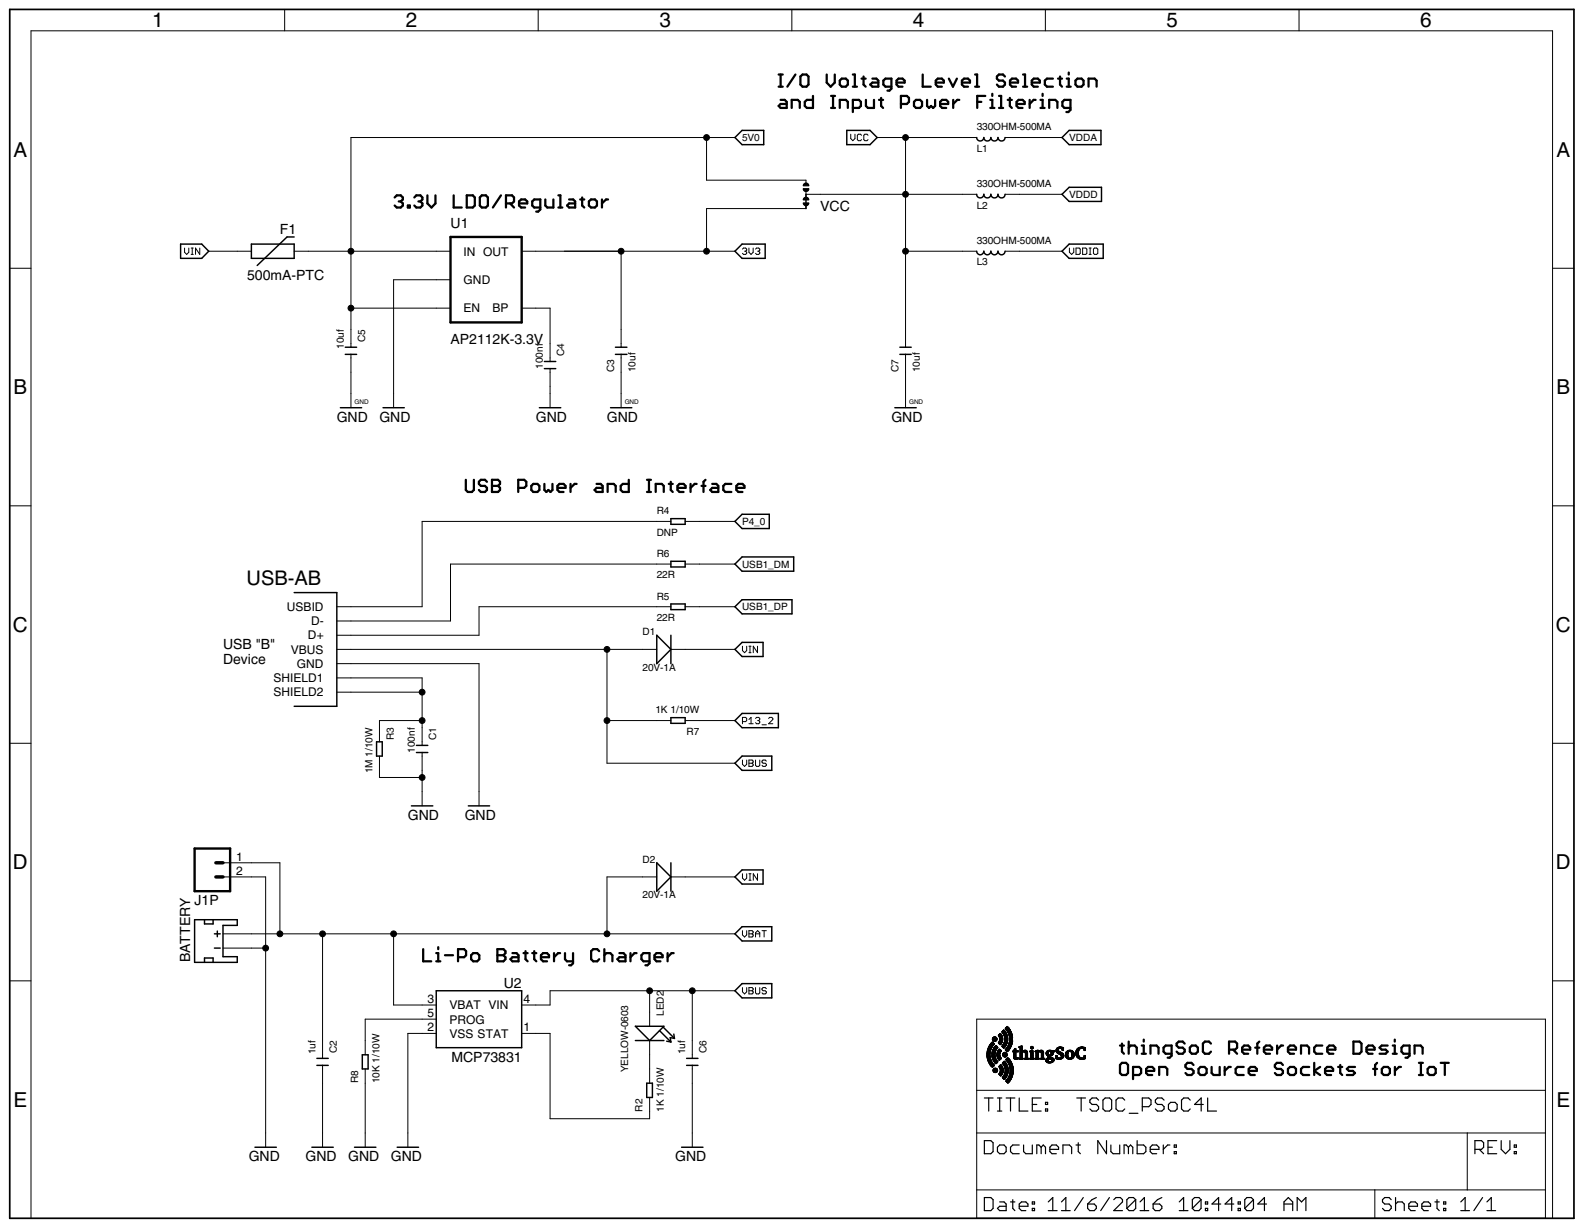
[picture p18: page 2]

100nf 1uf 100nf 1uf 1uf GND GND GND 10K 1/10W 100nf 1uf GND 1K 1/10W 10K 1/10W 10K 1/10W 1uf GNDGND 500mA-PTC GND GND 100nf 1M 1/10W GND GND GND GND 10uf GND GND GND 100nf GND 20V-1A MCP73831 GND GND GND 10K 1/10W 1K 1/10W GND 330OHM-500MA 330OHM-500MA 330OHM-500MA 1uf 20V-1A AP2112K-3.3V 10uf YELLOW-0603 GREEN-0603 GND1uf 22R 22R DNP 100nf GND10uf TSOC-PCB-SINGLE B3U-1000P-2P-SMD B3U-1000P-2P-SMD 1K 1/10W GND 3.2768KHZ 12pf 12pf GND GND OSCILLATOR5X3 GND FM24W256-G 100nf GND GND C8C9 C11 C10 C13 R11 C14 C15 R1 R10 R9 C12 F1 D+D- VBUS GND USBID SHIELD1 SHIELD2 C1R3 C5 P2_0 2 P2_1 3 P2_3 5 P2_4 6 P2_5 7 P2_7 9 VSSD 10 P3_0 12 P3_1 13 P3_2_SWD 14 P3_3_SWC 16 P3_4 17 P3_5 18 P3_7 20 VDDIO 21 P4_0 22 USBDP_P13_0 23 USBDN_P13_1 24 P7_0 26 P0_0 28 P0_1 29 P0_3 31 P0_4 32 P0_5 33 P0_7 35 XRES 36 VCCD 37 VSSD 38 VDDD 39 VSSA 41 P1_0 42 P1_1 43 P1_3 45 P1_4 46 P1_5 47 P1_6 48 P1_7/VREF 1 P2_2 4 P2_6 8 P3_6 19 P0_6 34 P1_2 44 P0_2 30 NC 11 NC 15 VBUS 25 P7_1 27 VDDA 40 C16 D2 U2 VIN 4 STAT 1 VBAT 3 PROG 5 VSS 2 BATTERY R8 J1P 12 R2 L3L2L1 C6 ATN 6B RI 1C DCD 2C DSR 3C DTR 4C TXD 8C IO2 1B IO1 2B RTS 5C CTS 6C IRQ 5B SS2 3B SS1 4B CS 7B MOSI 10B MISO 9B SCK 8B GND 12B AGND 12C 3V3 11B RXD 7C SDA 10C SCL 9C 5V0 11C D1 U1INGNDOUT EN BP C3 LED2 LED1 C2 R5R6R4 C4 C7 JTAG 1 2 3 4 5 6 7 8 9 10 11 12 13 14 15 16 VCC 1 1 2 2 RESET 1 1 2 2 USER R7 Y100 C101 C100 OSCEN GND VCC OUT VSS 4 WP 7 VCC 8 SCL 6 SDA 5 A2 3 A0 1 A1 2 U100 C102 GND GND GND P1_2 P1_7 P1_6 P1_5 P1_4 P1_3 P1_1 P1_0 P2_0 P2_1 P2_2 P2_3 P2_4 P2_5 P2_6 P2_7 P3_0 P3_1 P3_2 P3_3 P3_4 P3_5 P3_6 P3_7 P4_0 P4_0 P0_0 P0_1 P0_2 P0_3 P0_4 P0_5 P0_6 P0_7 XRES VCCD VCCD 5V0 USB1_DM USB1_DM USB1_DP USB1_DP P7_1 P7_0 VDDIO VDDIO VDDA VDDA VDDD VDDD ABCDE ABCDE 1 2 3 4 5 6 ABCDE ABCDE 1 2 3 4 5 6 ABCDE ABCDE 1 2 3 4 5 6 ABCDE ABCDE 1 2 3 4 5 6 USB-AB GND GND GND GND GND GND Internal/Core Bypass Digital Bypass VDDIO Bypass SAR Bypass USB "B" Device Reset Pullup Heartbeat LED Analog Bypass I2C Pullups Switches 32,768 KHz Crystal (WCO/RTC Clock)

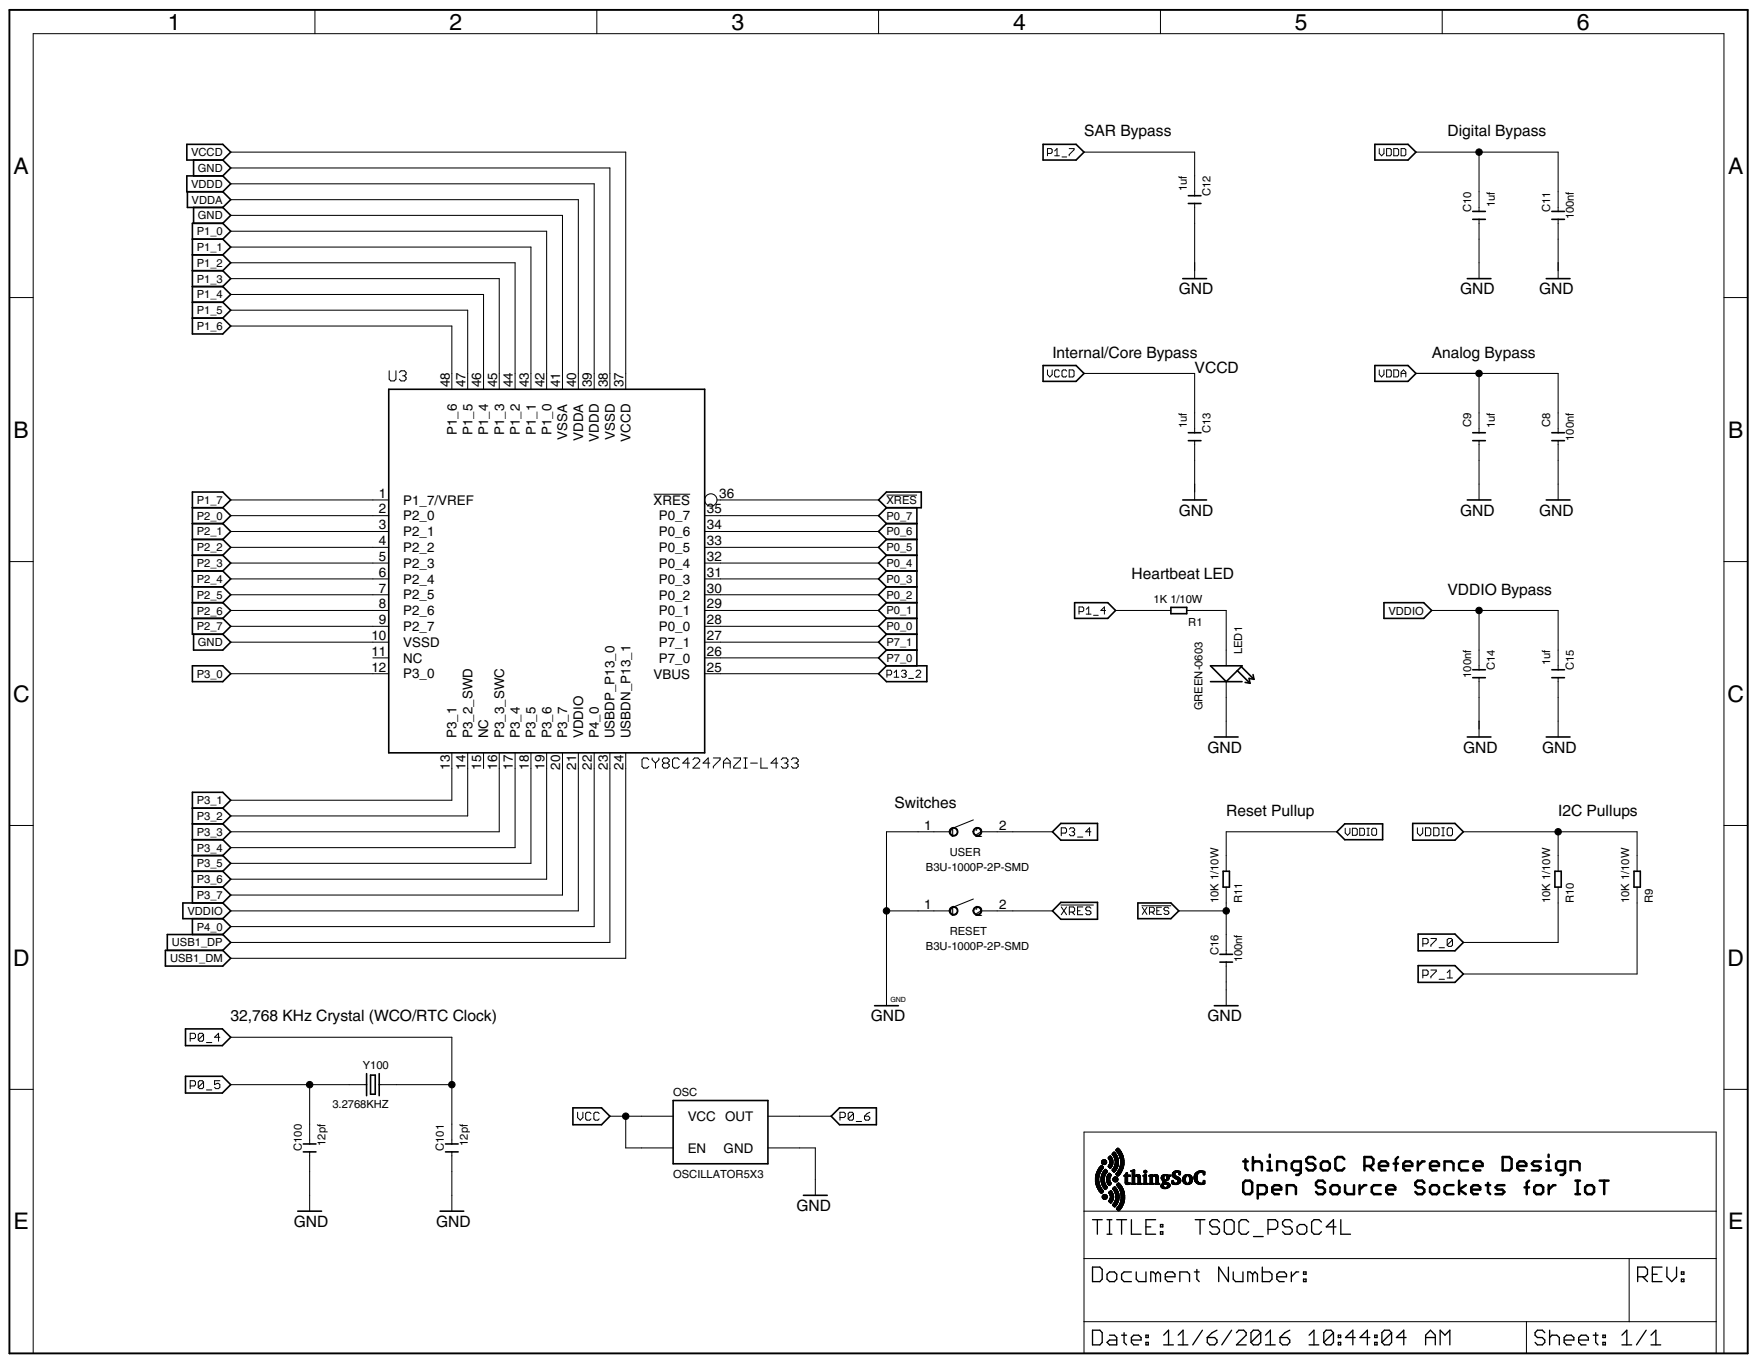
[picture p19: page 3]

32,768 KHz Crystal (WCO/RTC Clock)

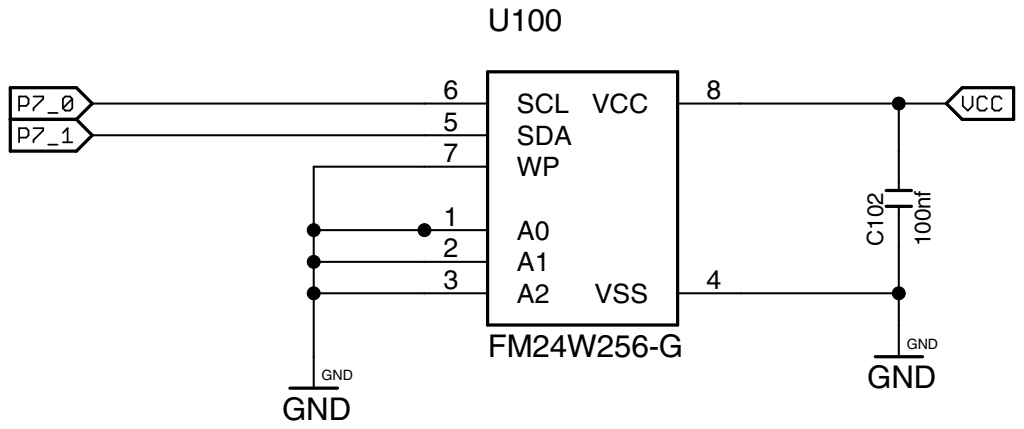
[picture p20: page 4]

100nf 1uf 100nf 1uf 1uf GND GND GND 10K 1/10W 100nf 1uf GND 1K 1/10W 10K 1/10W 10K 1/10W 1uf GNDGND 500mA-PTC GND GND 100nf 1M 1/10W GND GND GND GND 10uf GND GND GND 100nf GND 20V-1A MCP73831 GND GND GND 10K 1/10W 1K 1/10W GND 330OHM-500MA 330OHM-500MA 330OHM-500MA 1uf 20V-1A AP2112K-3.3V 10uf YELLOW-0603 GREEN-0603 GND1uf 22R 22R DNP 100nf GND10uf TSOC-PCB-SINGLE B3U-1000P-2P-SMD B3U-1000P-2P-SMD 1K 1/10W GND 3.2768KHZ 12pf 12pf GND GND OSCILLATOR5X3 GND FM24W256-G 100nf GND GND C8C9 C11 C10 C13 R11 C14 C15 R1 R10 R9 C12 F1 D+D- VBUS GND USBID SHIELD1 SHIELD2 C1R3 C5 P2_0 2 P2_1 3 P2_3 5 P2_4 6 P2_5 7 P2_7 9 VSSD 10 P3_0 12 P3_1 13 P3_2_SWD 14 P3_3_SWC 16 P3_4 17 P3_5 18 P3_7 20 VDDIO 21 P4_0 22 USBDP_P13_0 23 USBDN_P13_1 24 P7_0 26 P0_0 28 P0_1 29 P0_3 31 P0_4 32 P0_5 33 P0_7 35 XRES 36 VCCD 37 VSSD 38 VDDD 39 VSSA 41 P1_0 42 P1_1 43 P1_3 45 P1_4 46 P1_5 47 P1_6 48 P1_7/VREF 1 P2_2 4 P2_6 8 P3_6 19 P0_6 34 P1_2 44 P0_2 30 NC 11 NC 15 VBUS 25 P7_1 27 VDDA 40 C16 D2 U2 VIN 4 STAT 1 VBAT 3 PROG 5 VSS 2 BATTERY R8 J1P 12 R2 L3L2L1 C6 ATN 6B RI 1C DCD 2C DSR 3C DTR 4C TXD 8C IO2 1B IO1 2B RTS 5C CTS 6C IRQ 5B SS2 3B SS1 4B CS 7B MOSI 10B MISO 9B SCK 8B GND 12B AGND 12C 3V3 11B RXD 7C SDA 10C SCL 9C 5V0 11C D1 U1INGNDOUT EN BP C3 LED2 LED1 C2 R5R6R4 C4 C7 JTAG 1 2 3 4 5 6 7 8 9 10 11 12 13 14 15 16 VCC 1 1 2 2 RESET 1 1 2 2 USER R7 Y100 C101 C100 OSCEN GND VCC OUT VSS 4 WP 7 VCC 8 SCL 6 SDA 5 A2 3 A0 1 A1 2 U100 C102 GND GND GND P1_2 P1_7 P1_6 P1_5 P1_4 P1_3 P1_1 P1_0 P2_0 P2_1 P2_2 P2_3 P2_4 P2_5 P2_6 P2_7 P3_0 P3_1 P3_2 P3_3 P3_4 P3_5 P3_6 P3_7 P4_0 P4_0 P0_0 P0_1 P0_2 P0_3 P0_4 P0_5 P0_6 P0_7 XRES VCCD VCCD 5V0 USB1_DM USB1_DM USB1_DP USB1_DP P7_1 P7_0 VDDIO VDDIO VDDA VDDA VDDD VDDD ABCDE ABCDE 1 2 3 4 5 6 ABCDE ABCDE 1 2 3 4 5 6 ABCDE ABCDE 1 2 3 4 5 6 ABCDE ABCDE 1 2 3 4 5 6 USB-AB GND GND GND GND GND GND Internal/Core Bypass Digital Bypass VDDIO Bypass SAR Bypass USB "B" Device Reset Pullup Heartbeat LED Analog Bypass I2C Pullups Switches 32,768 KHz Crystal (WCO/RTC Clock)

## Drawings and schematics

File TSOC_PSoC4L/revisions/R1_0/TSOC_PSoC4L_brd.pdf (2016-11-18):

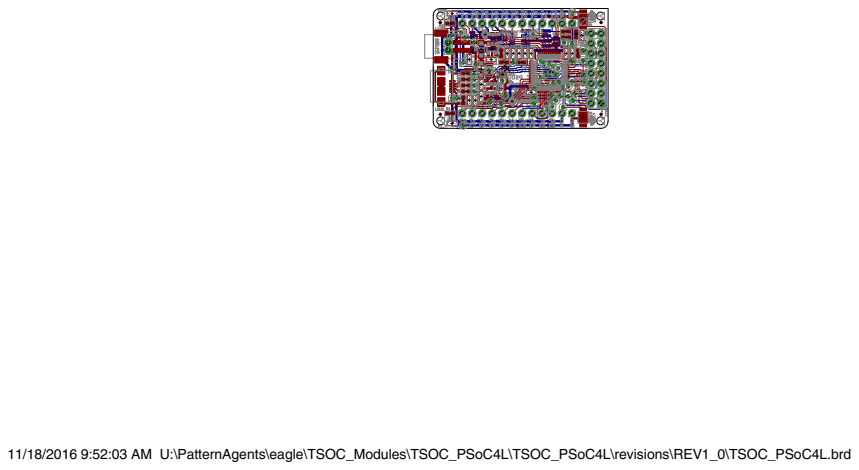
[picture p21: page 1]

11/18/2016 9:52:03 AM U:\PatternAgents\eagle\TSOC_Modules\TSOC_PSoC4L\TSOC_PSoC4L\revisions\REV1_0\TSOC_PSoC4L.brd

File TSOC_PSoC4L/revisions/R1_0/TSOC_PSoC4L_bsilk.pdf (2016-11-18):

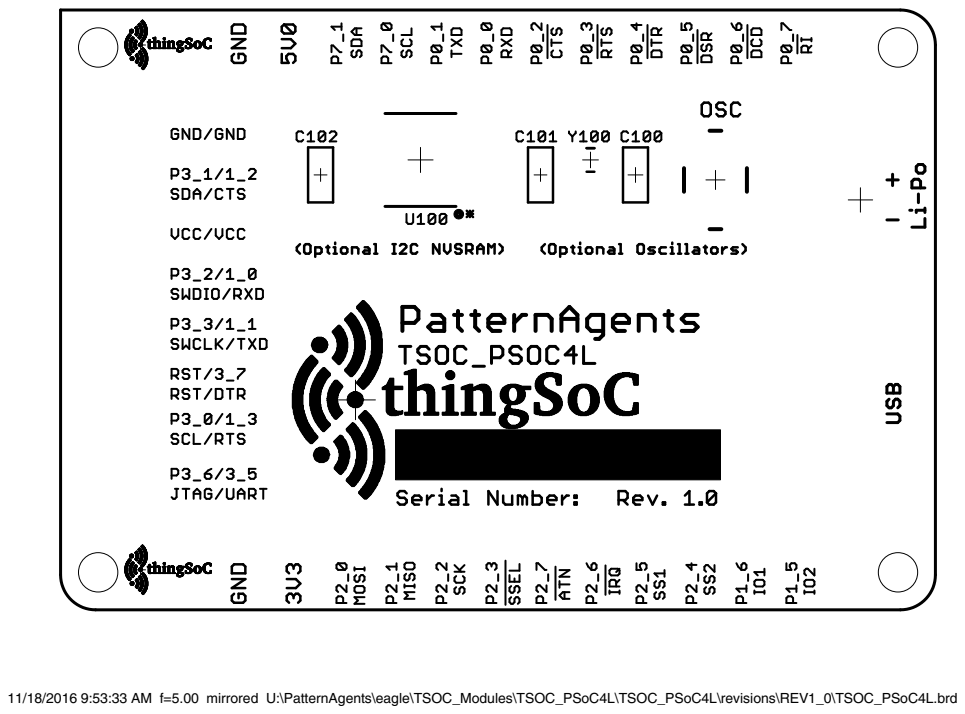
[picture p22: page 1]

11/18/2016 9:53:33 AM f=5.00 mirrored U:\PatternAgents\eagle\TSOC_Modules\TSOC_PSoC4L\TSOC_PSoC4L\revisions\REV1_0\TSOC_PSoC4L.brd

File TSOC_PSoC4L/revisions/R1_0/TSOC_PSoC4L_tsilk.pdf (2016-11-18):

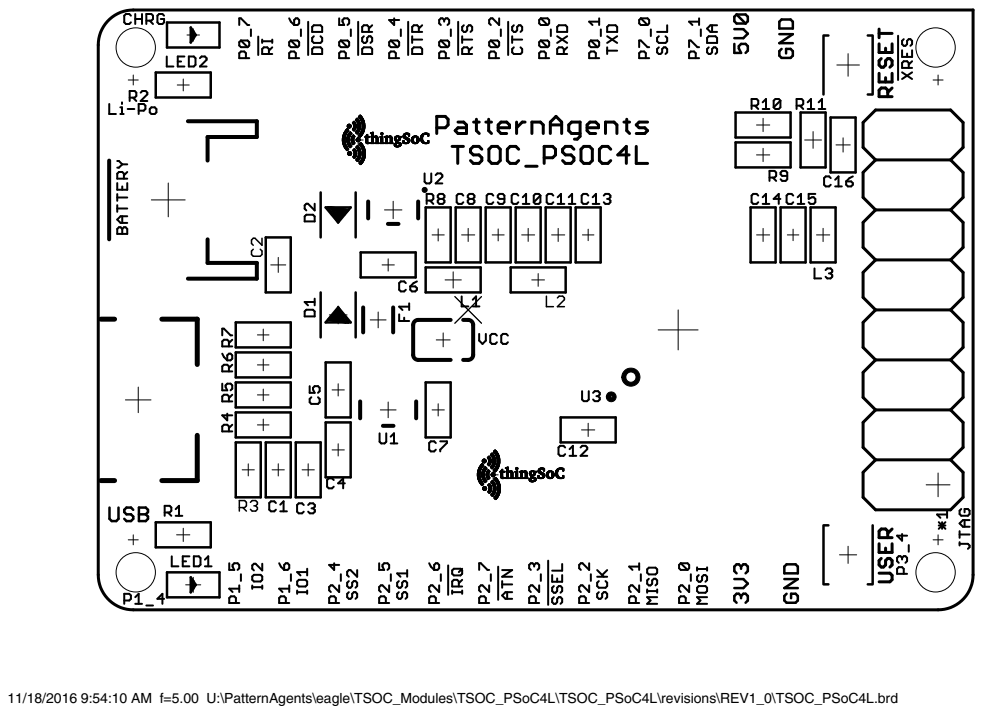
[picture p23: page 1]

11/18/2016 9:54:10 AM f=5.00 U:\PatternAgents\eagle\TSOC_Modules\TSOC_PSoC4L\TSOC_PSoC4L\revisions\REV1_0\TSOC_PSoC4L.brd

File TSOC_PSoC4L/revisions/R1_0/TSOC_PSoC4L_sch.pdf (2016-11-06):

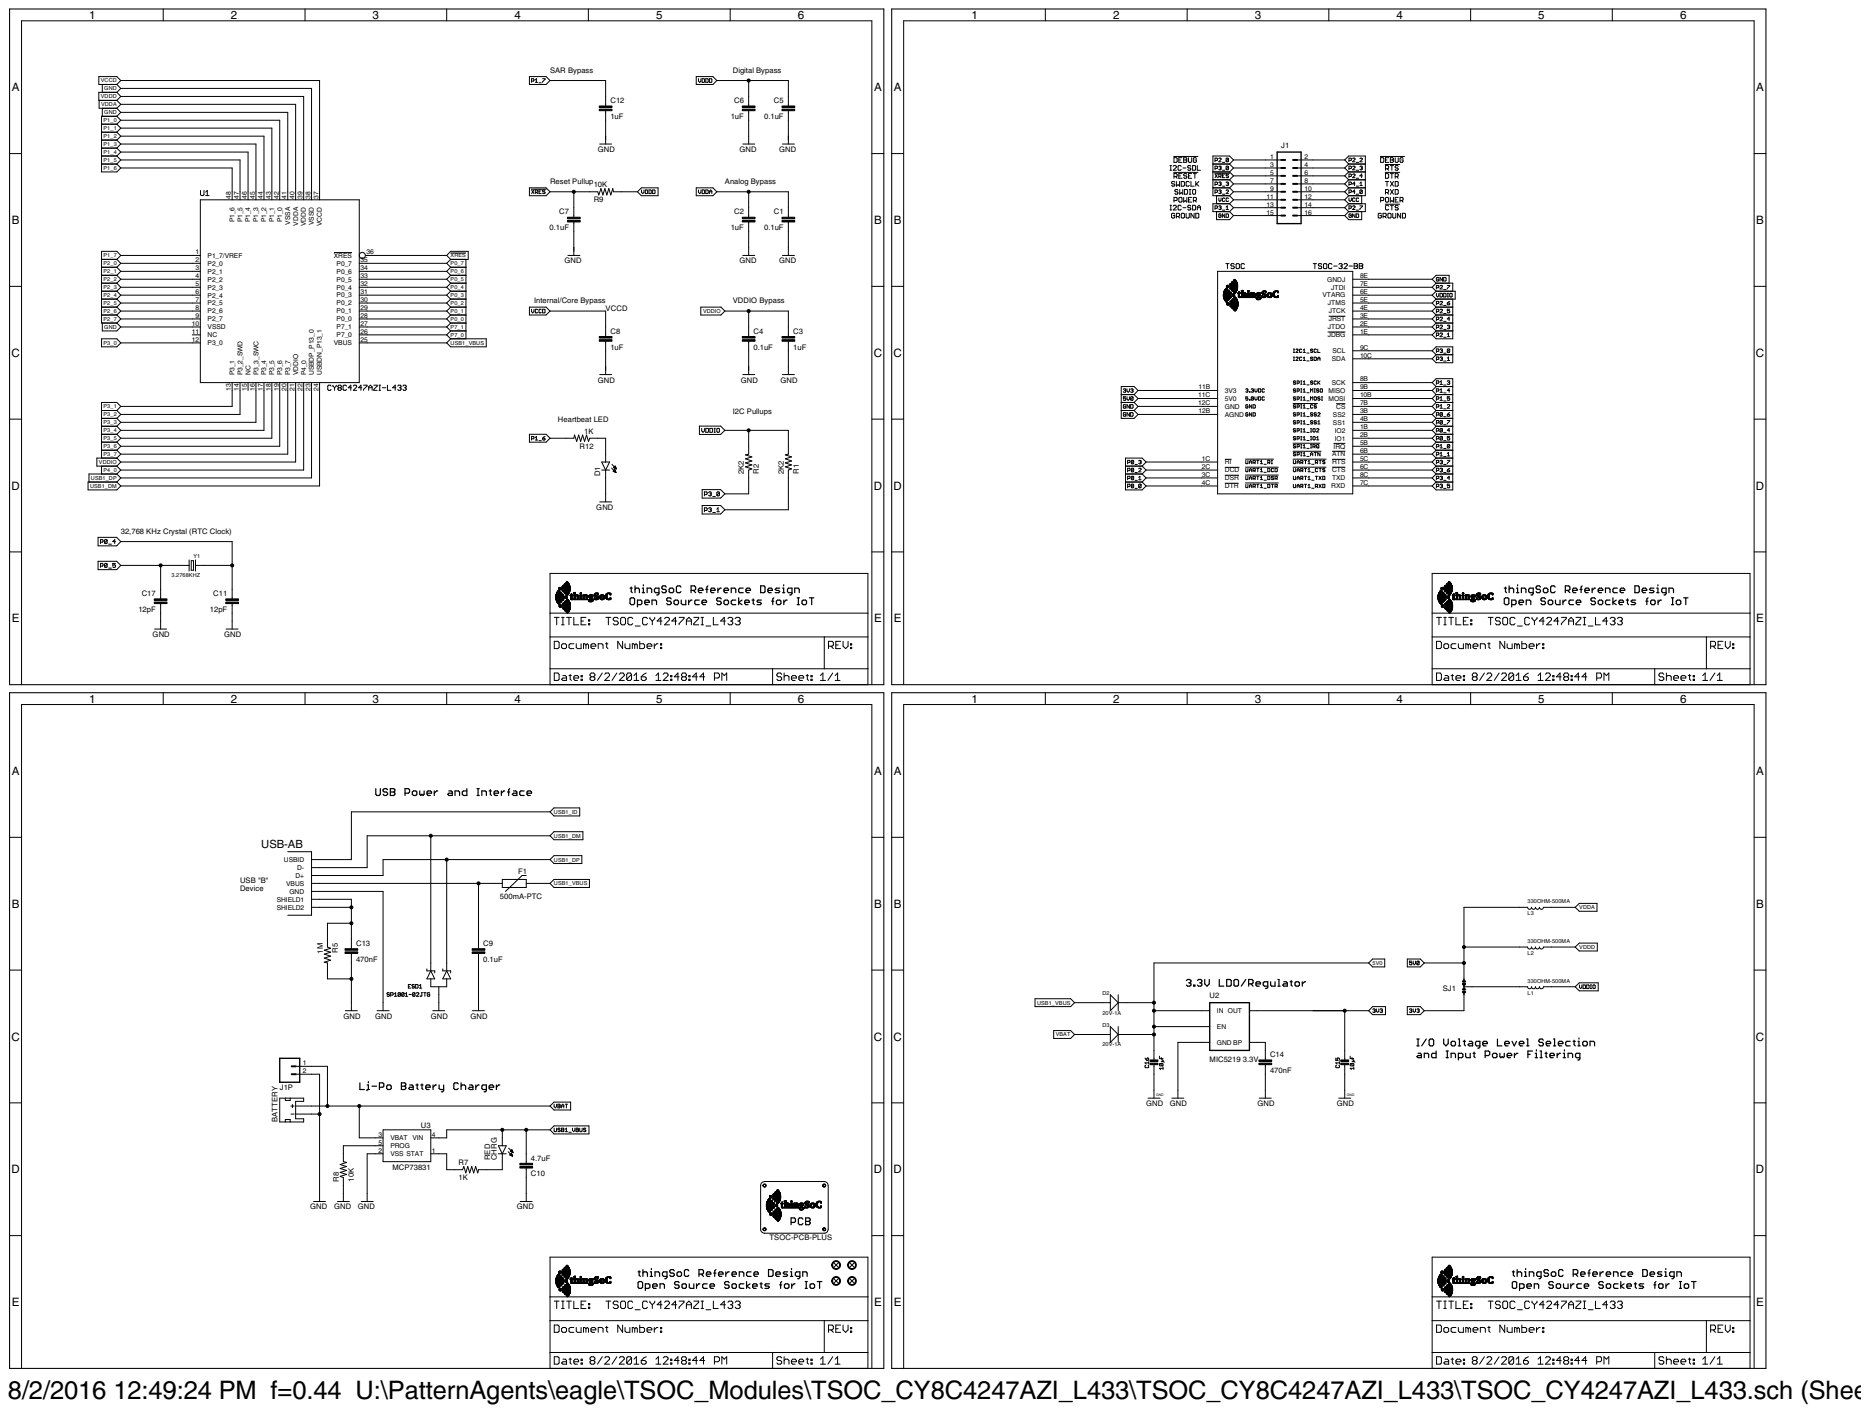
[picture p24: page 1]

32,768 KHz Crystal (RTC Clock)

B | USB1_DM | B

8/2/2016 12:49:24 PM f=0.44 U:\PatternAgents\eagle\TSOC_Modules\TSOC_CY8C4247AZI_L433\TSOC_CY8C4247AZI_L433\TSOC_CY4247AZI_L433.sch (Sheet: 1/1)

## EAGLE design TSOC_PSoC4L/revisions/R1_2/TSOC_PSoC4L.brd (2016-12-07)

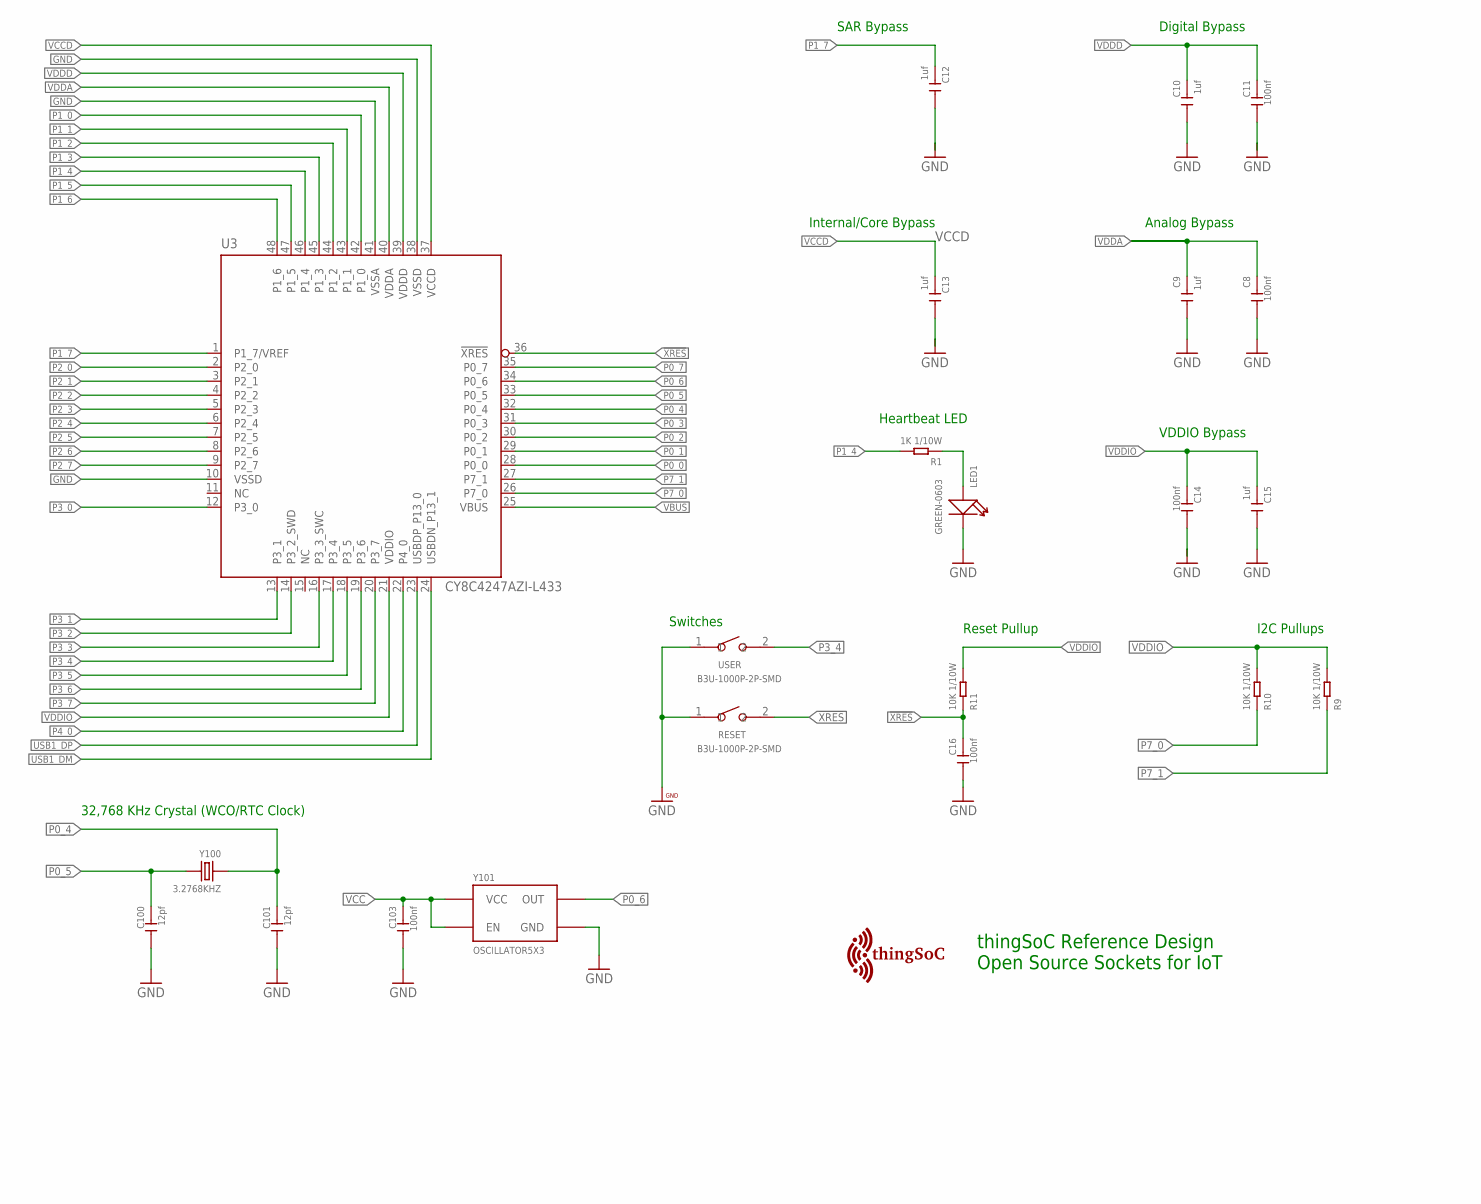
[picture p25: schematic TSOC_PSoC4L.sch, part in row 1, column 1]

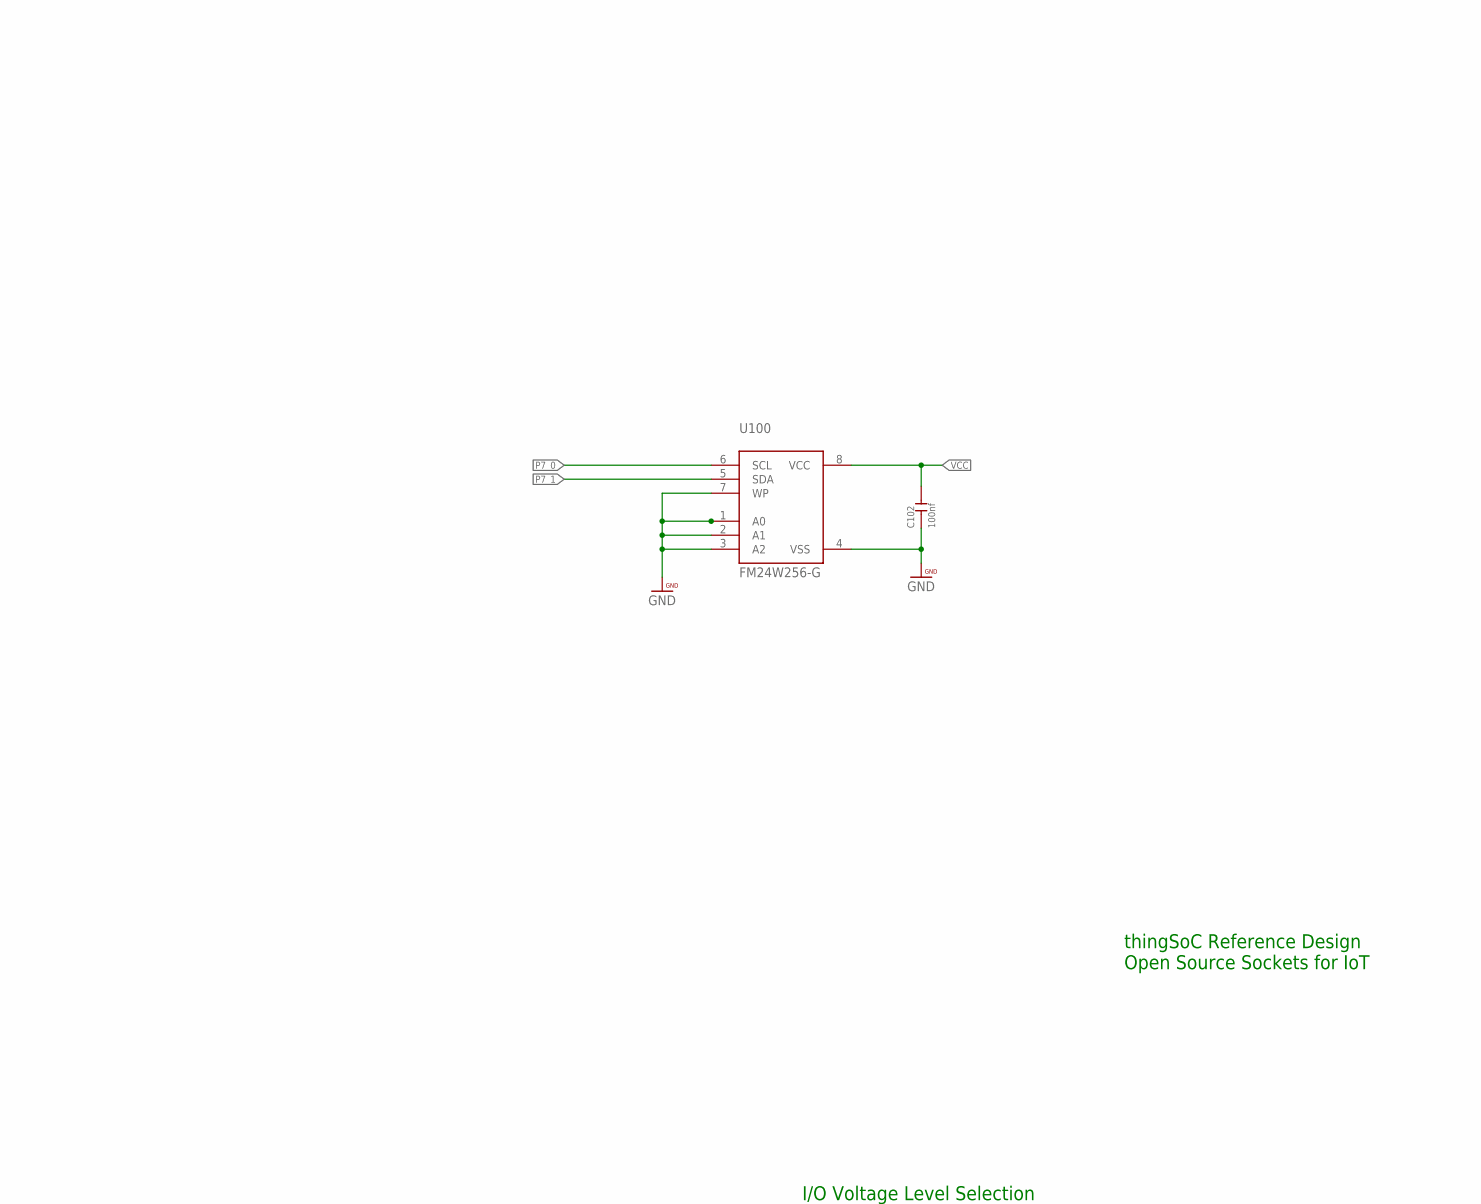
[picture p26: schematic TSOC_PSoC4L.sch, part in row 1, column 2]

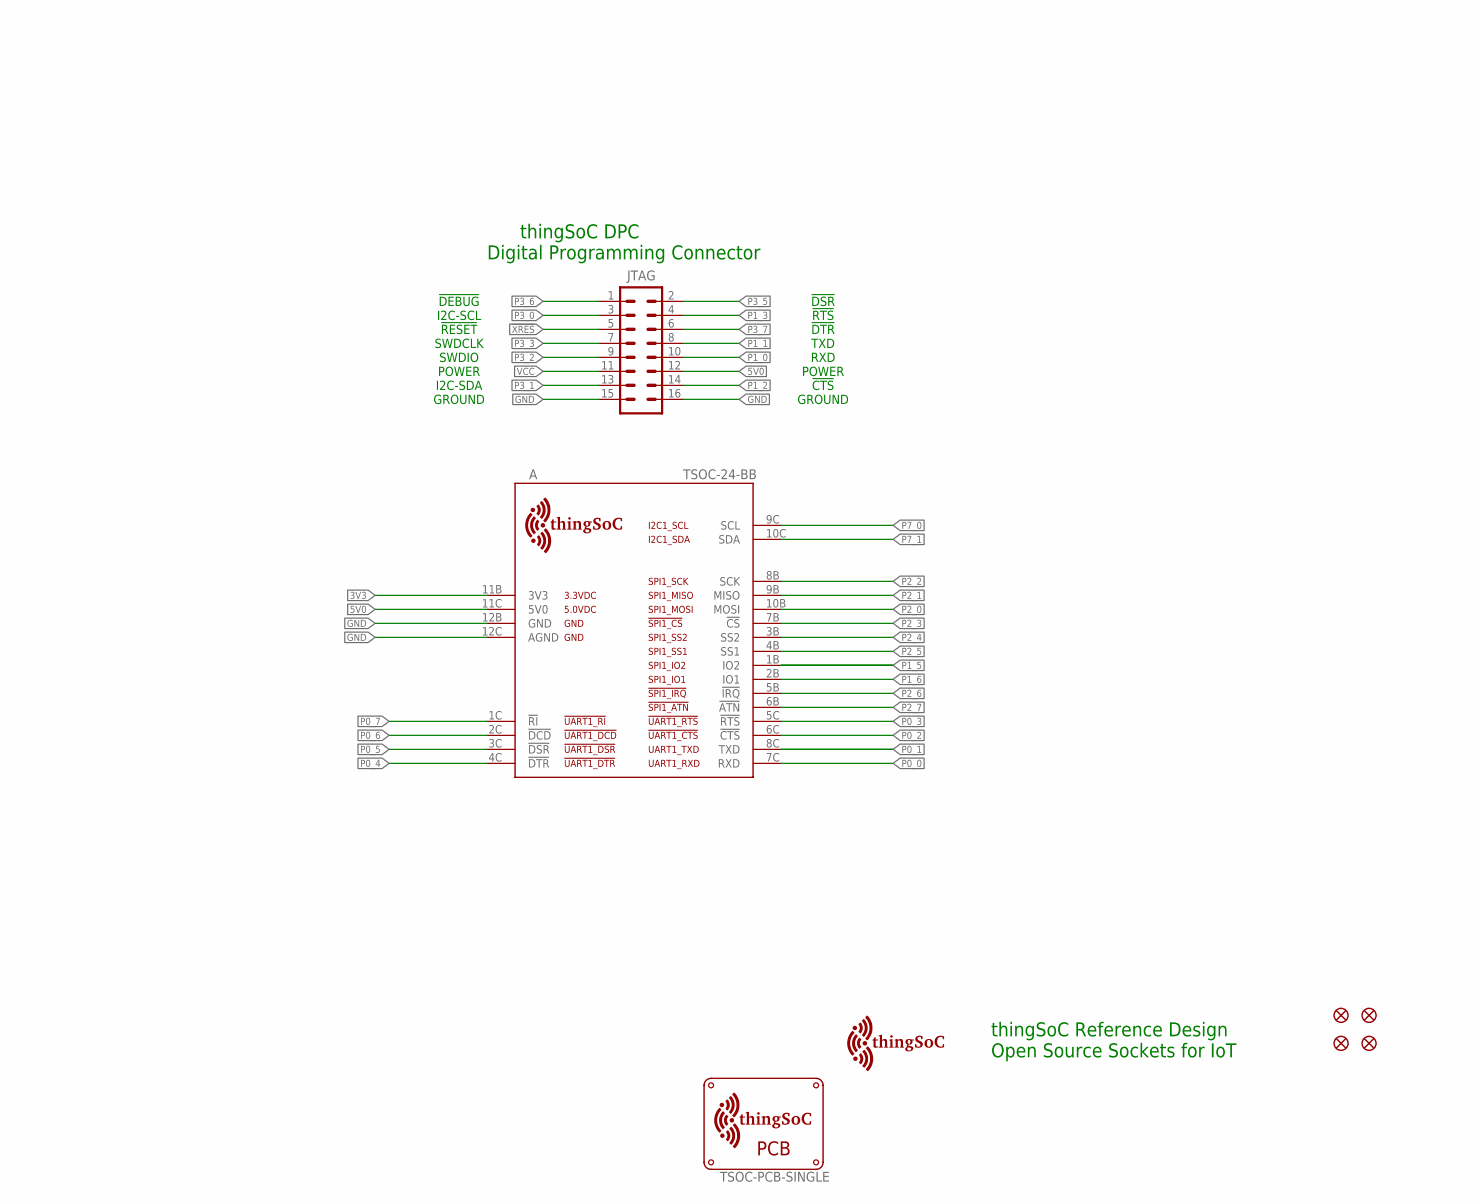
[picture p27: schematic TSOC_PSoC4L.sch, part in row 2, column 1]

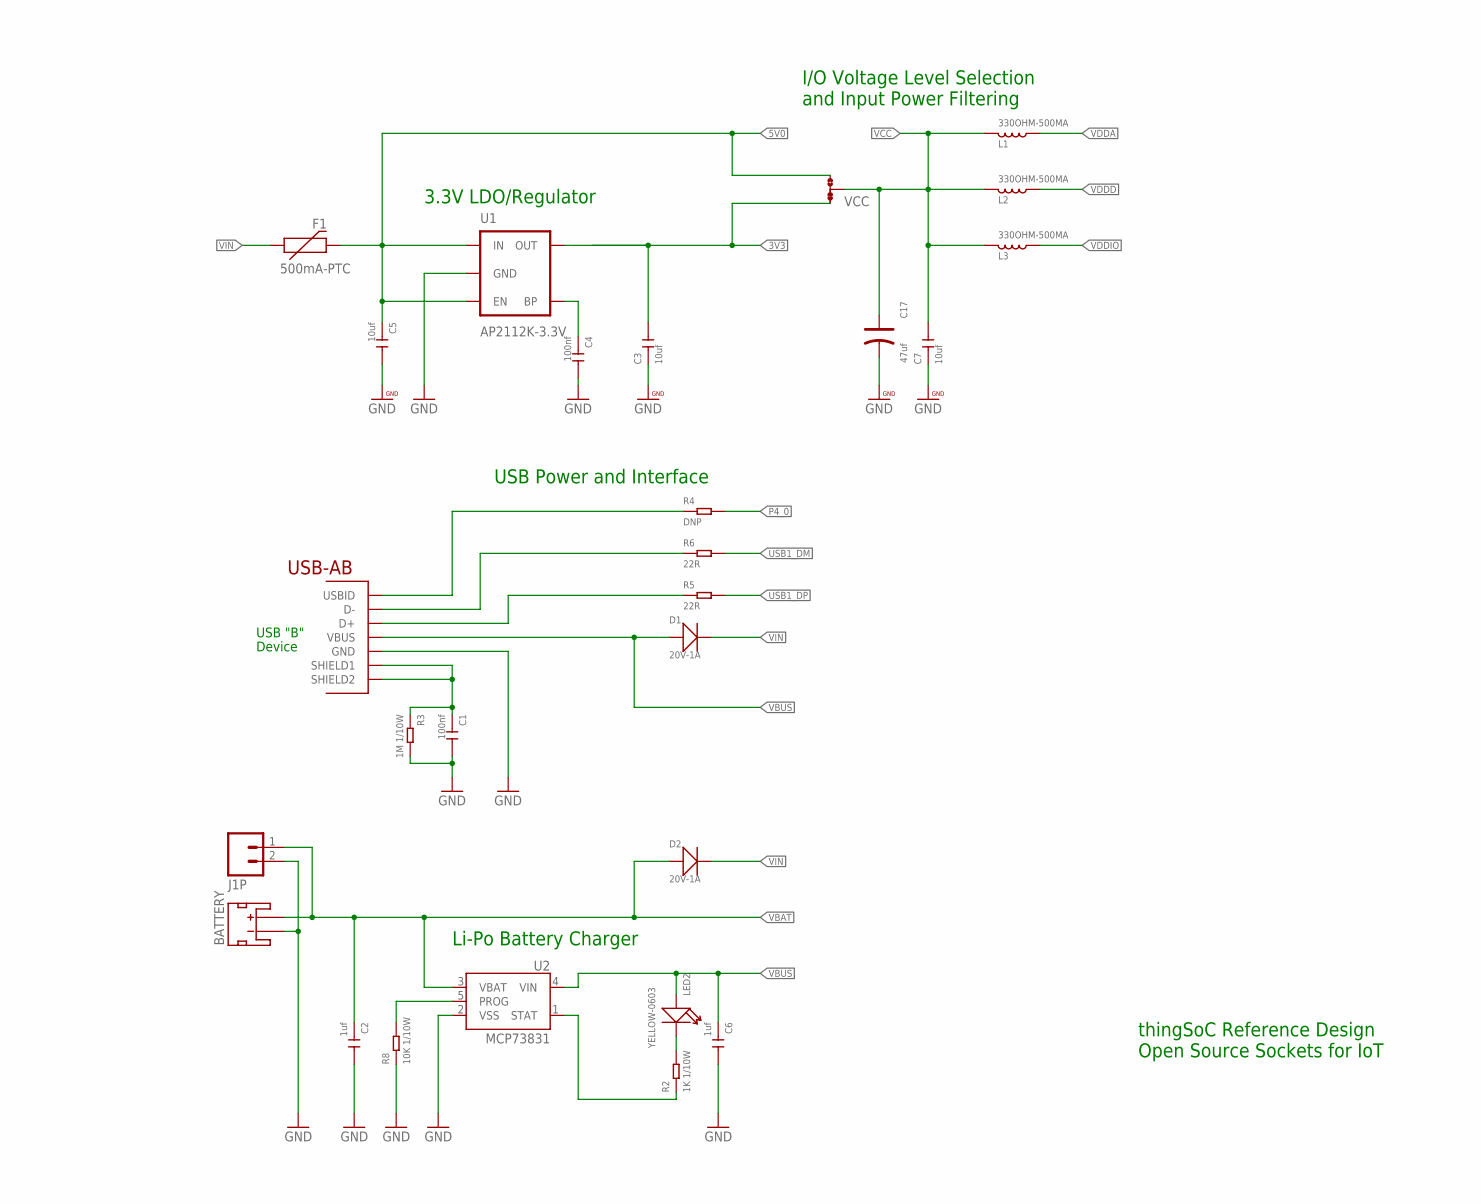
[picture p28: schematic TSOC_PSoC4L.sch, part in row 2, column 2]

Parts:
A: TSOC-24-BB; TSOC-BB-S24
BATTERY: JST_2MM_MALE; JST-2-SMD
C1, C4, C8, C11, C14, C16, C102, C103: 100nf; C0603
C2, C6, C9, C10, C12, C13, C15: 1uf; C0603
C3, C5, C7: 10uf; C0603
C17: 47uf; AVX-A
C100, C101: 12pf; C0603
D1, D2: 20V-1A; SOD-123
F1: 500mA-PTC; PTC-1206
FID1, FID2, FID3, FID4: FIDUCIALUFIDUCIAL; MICRO-FIDUCIAL
J1P: M02-JST-2-PTH-NO_SILK; JST-2-PTH-NS
JTAG: M08X2; 2X8
L1, L2, L3: 330OHM-500MA; L0603
LED1: GREEN-0603; LED-0603
LED2: YELLOW-0603; LED-0603
R1, R2: 1K 1/10W; R0603
R3: 1M 1/10W; R0603
R4: DNP; R0603
R5, R6: 22R; R0603
R8, R9, R10, R11: 10K 1/10W; R0603
RESET: B3U-1000P-2P-SMD; SW2-2.6-3.0X2.5X1.2+0.4MM
U1: AP2112K-3.3V; SOT23-5
U2: MCP73831; SOT23-5
U3: CY8C4247AZI-L433; TQFP-7X7-48
U100: FM24W256-G; SO08
U$1: TSOC-PCB-SINGLE; TSOC-BB-BRD-DIM
U$100: TSOC-LOGO-LRG
U$101: TSOC-LOGO-SMALL; TSOC-LOGO-SML
USB: USB_AB; USB-AB-MICRO-SMD
USER: B3U-1000P-2P-SMD; SW2-2.6-3.0X2.5X1.2+0.4MM
VCC: JMP-3-1_2
Y100: 3.2768KHZ; X2-SMD-L2.0X1.2X0.55MM
Y101: OSCILLATOR5X3; CRYSTAL-SMD-5X3

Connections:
3V3: A.11B (3V3), C3.2, U1.5 (OUT), VCC.1
5V0: A.11C (5V0), C5.1, F1.2, JTAG.12, U1.1 (IN), U1.3 (EN), VCC.3
!XRES: C16.1, JTAG.5, R11.1, RESET.2, U3.36 (!XRES)
BYPASS1: C4.1, U1.4 (BP)
CLED: LED2.-, R2.2
CSTAT: R2.1, U2.1 (STAT)
GND: A.12B (GND), A.12C (AGND), BATTERY.1 (-), C1.2, C2.2, C3.1, C4.2, C5.2, C6.2, C7.1, C8.2, C9.2, C10.2, C11.2, C12.2, C13.2, C14.2, C15.2, C16.2, C17.-, C100.2, C101.2, C102.1, C103.2, J1P.2, JTAG.15, JTAG.16, LED1.-, R3.2, R8.1, RESET.1, U1.2 (GND), U2.2 (VSS), U3.10 (VSSD), U3.38 (VSSD), U3.41 (VSSA), U100.1 (A0), U100.2 (A1), U100.3 (A2), U100.4 (VSS), U100.7 (WP), USB.GND, USER.1, Y101.2 (GND)
unnamed: R8.2, U2.5 (PROG)
unnamed: LED1.+, R1.1
P0_0: A.7C (RXD), U3.28 (P0_0)
P0_1: A.8C (TXD), U3.29 (P0_1)
P0_2: A.6C (!CTS), U3.30 (P0_2)
P0_3: A.5C (!RTS), U3.31 (P0_3)
P0_4: A.4C (!DTR), C101.1, U3.32 (P0_4), Y100.1
P0_5: A.3C (!DSR), C100.1, U3.33 (P0_5), Y100.2
P0_6: A.2C (!DCD), U3.34 (P0_6), Y101.3 (OUT)
P0_7: A.1C (!RI), U3.35 (P0_7)
P1_0: JTAG.10, U3.42 (P1_0)
P1_1: JTAG.8, U3.43 (P1_1)
P1_2: JTAG.14, U3.44 (P1_2)
P1_3: JTAG.4, U3.45 (P1_3)
P1_4: R1.2, U3.46 (P1_4)
P1_5: A.1B (IO2), U3.47 (P1_5)
P1_6: A.2B (IO1), U3.48 (P1_6)
P1_7: C12.1, U3.1 (P1_7/VREF)
P2_0: A.10B (MOSI), U3.2 (P2_0)
P2_1: A.9B (MISO), U3.3 (P2_1)
P2_2: A.8B (SCK), U3.4 (P2_2)
P2_3: A.7B (!CS), U3.5 (P2_3)
P2_4: A.3B (SS2), U3.6 (P2_4)
P2_5: A.4B (SS1), U3.7 (P2_5)
P2_6: A.5B (!IRQ), U3.8 (P2_6)
P2_7: A.6B (!ATN), U3.9 (P2_7)
P3_0: JTAG.3, U3.12 (P3_0)
P3_1: JTAG.13, U3.13 (P3_1)
P3_2: JTAG.9, U3.14 (P3_2_SWD)
P3_3: JTAG.7, U3.16 (P3_3_SWC)
P3_4: U3.17 (P3_4), USER.2
P3_5: JTAG.2, U3.18 (P3_5)
P3_6: JTAG.1, U3.19 (P3_6)
P3_7: JTAG.6, U3.20 (P3_7)
P4_0: R4.2, U3.22 (P4_0)
P7_0: A.9C (SCL), R10.1, U3.26 (P7_0), U100.6 (SCL)
P7_1: A.10C (SDA), R9.1, U3.27 (P7_1), U100.5 (SDA)
USB1_DM: R6.2, U3.24 (USBDN_P13_1)
USB1_DP: R5.2, U3.23 (USBDP_P13_0)
USB1_I: R4.1, USB.ID (USBID)
USB1_M: R6.1, USB.D-
USB1_P: R5.1, USB.D+
USB1_SHIELD: C1.1, R3.1, USB.SHIELD1, USB.SHIELD2
VBAT: BATTERY.2 (+), C2.1, D2.+, J1P.1, U2.3 (VBAT)
VBUS: C6.1, D1.+, LED2.+, U2.4 (VIN), U3.25 (VBUS), USB.VBUS
VCC: C7.2, C17.+, C102.2, C103.1, JTAG.11, L1.1, L2.1, L3.1, U100.8 (VCC), VCC.2, Y101.1 (EN), Y101.4 (VCC)
VCCD: C13.1, U3.37 (VCCD)
VDDA: C8.1, C9.1, L1.2, U3.40 (VDDA)
VDDD: C10.1, C11.1, L2.2, U3.39 (VDDD)
VDDIO: C14.1, C15.1, L3.2, R9.2, R10.2, R11.2, U3.21 (VDDIO)
VIN: D1.-, D2.-, F1.1

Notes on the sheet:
Internal/Core Bypass
Digital Bypass
VDDIO Bypass
SAR Bypass
USB "B"
Device
3.3V LDO/Regulator
Reset Pullup
Heartbeat LED
Analog Bypass
Li-Po Battery Charger
USB Power and Interface
I/O Voltage Level Selection and Input Power Filtering
I2C Pullups
thingSoC Reference Design Open Source Sockets for IoT
I2C-SDA
I2C-SCL
!RESET
SWDCLK
SWDIO
POWER
GROUND
!DEBUG
!DSR
!RTS
!CTS
!DTR
TXD
RXD
thingSoC DPC Digital Programming Connector
Switches
32,768 KHz Crystal (WCO/RTC Clock)

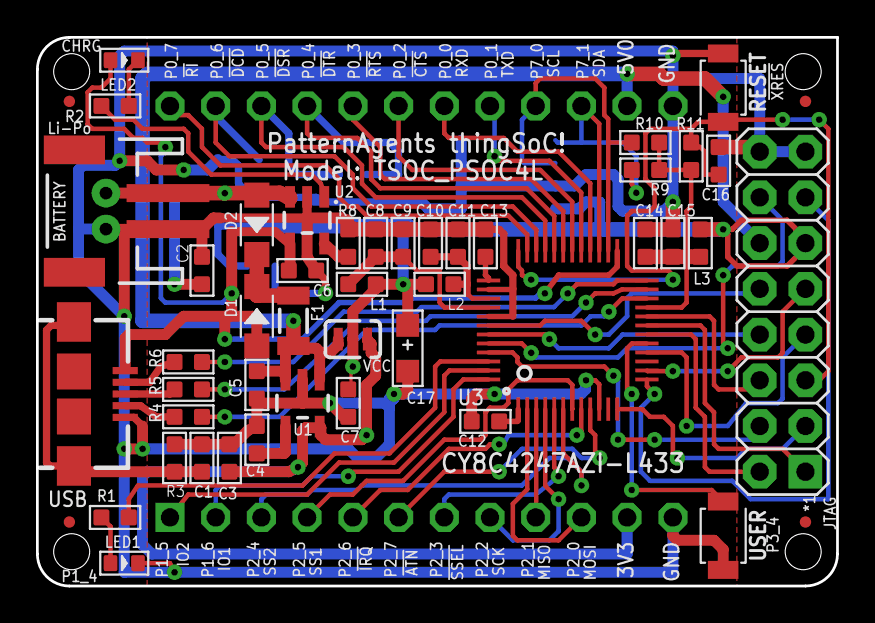
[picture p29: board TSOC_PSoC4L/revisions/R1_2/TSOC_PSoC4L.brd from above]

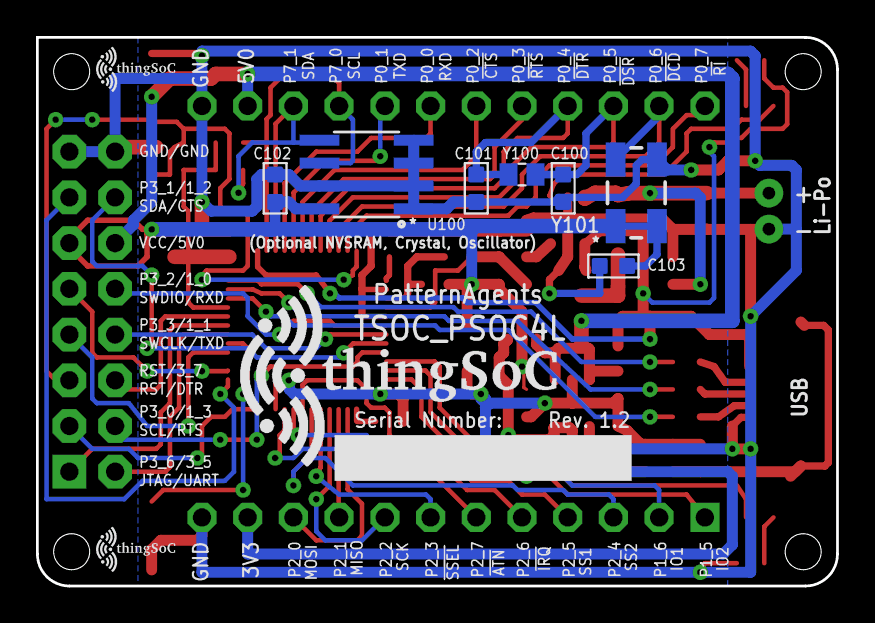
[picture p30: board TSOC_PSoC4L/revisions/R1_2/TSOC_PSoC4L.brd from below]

Board: 2 copper layers, 44.5 x 30.5 mm, 61 parts (11 on the bottom side), 58 nets.

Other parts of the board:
U$102: TSOC-LOGO-SMALL; TSOC-LOGO-SML

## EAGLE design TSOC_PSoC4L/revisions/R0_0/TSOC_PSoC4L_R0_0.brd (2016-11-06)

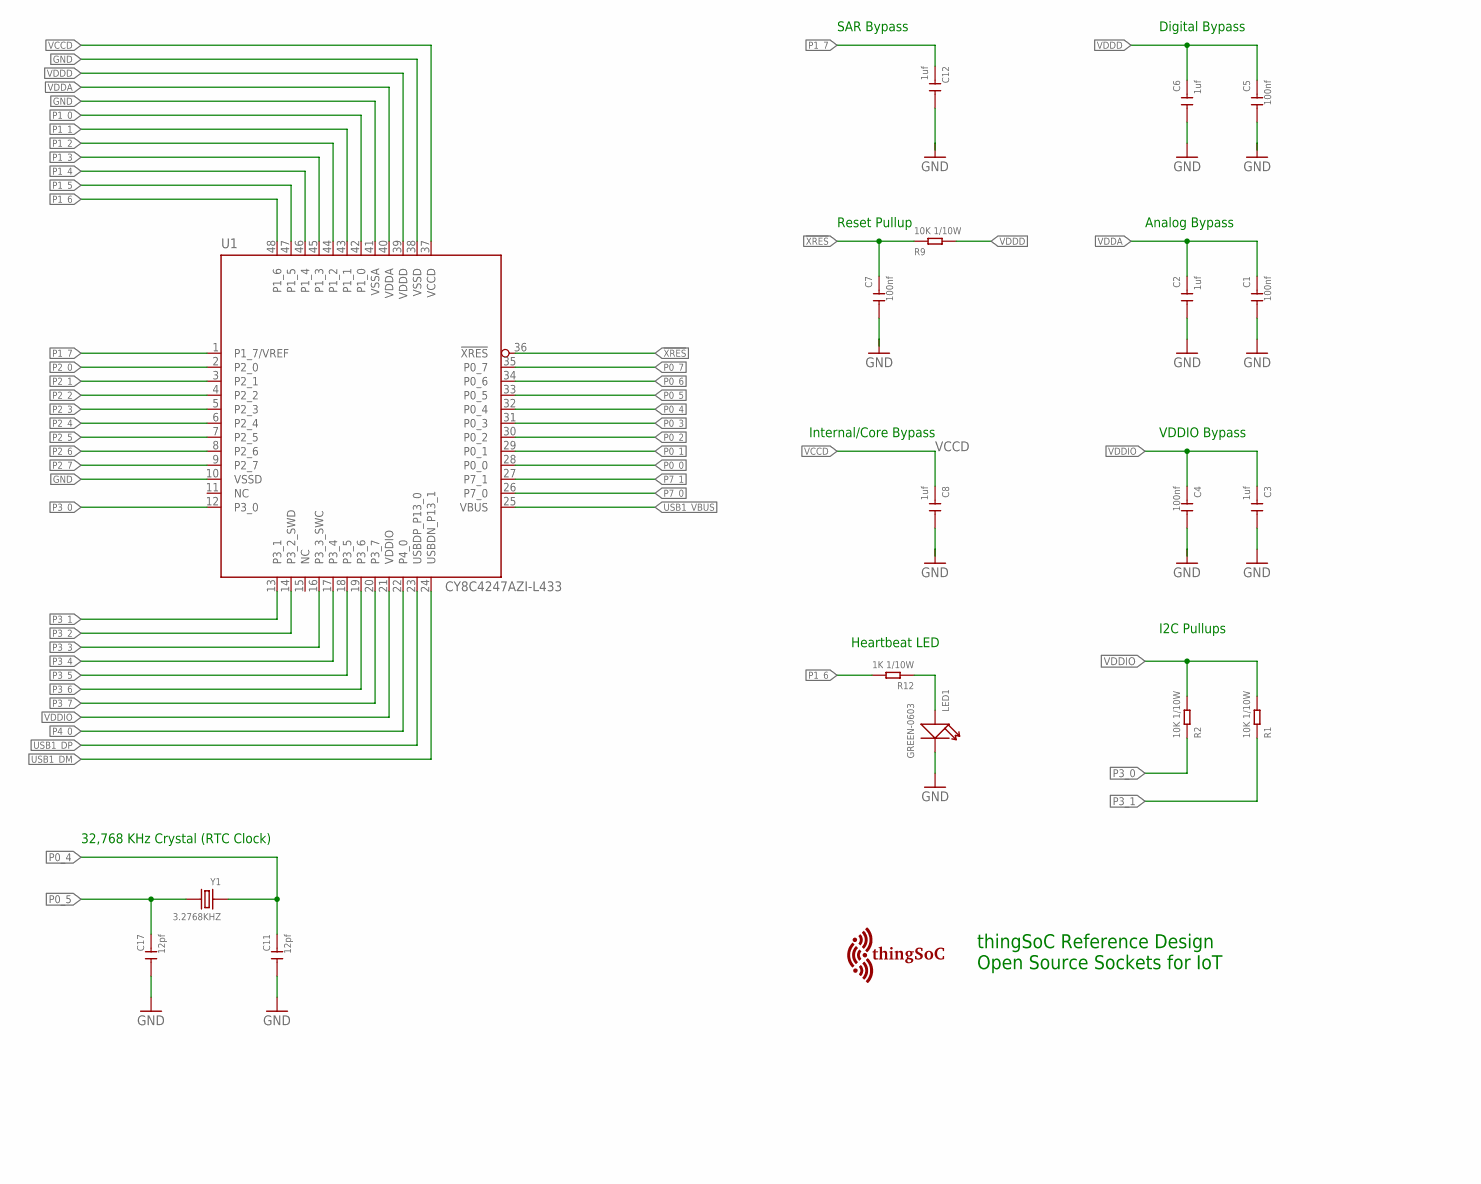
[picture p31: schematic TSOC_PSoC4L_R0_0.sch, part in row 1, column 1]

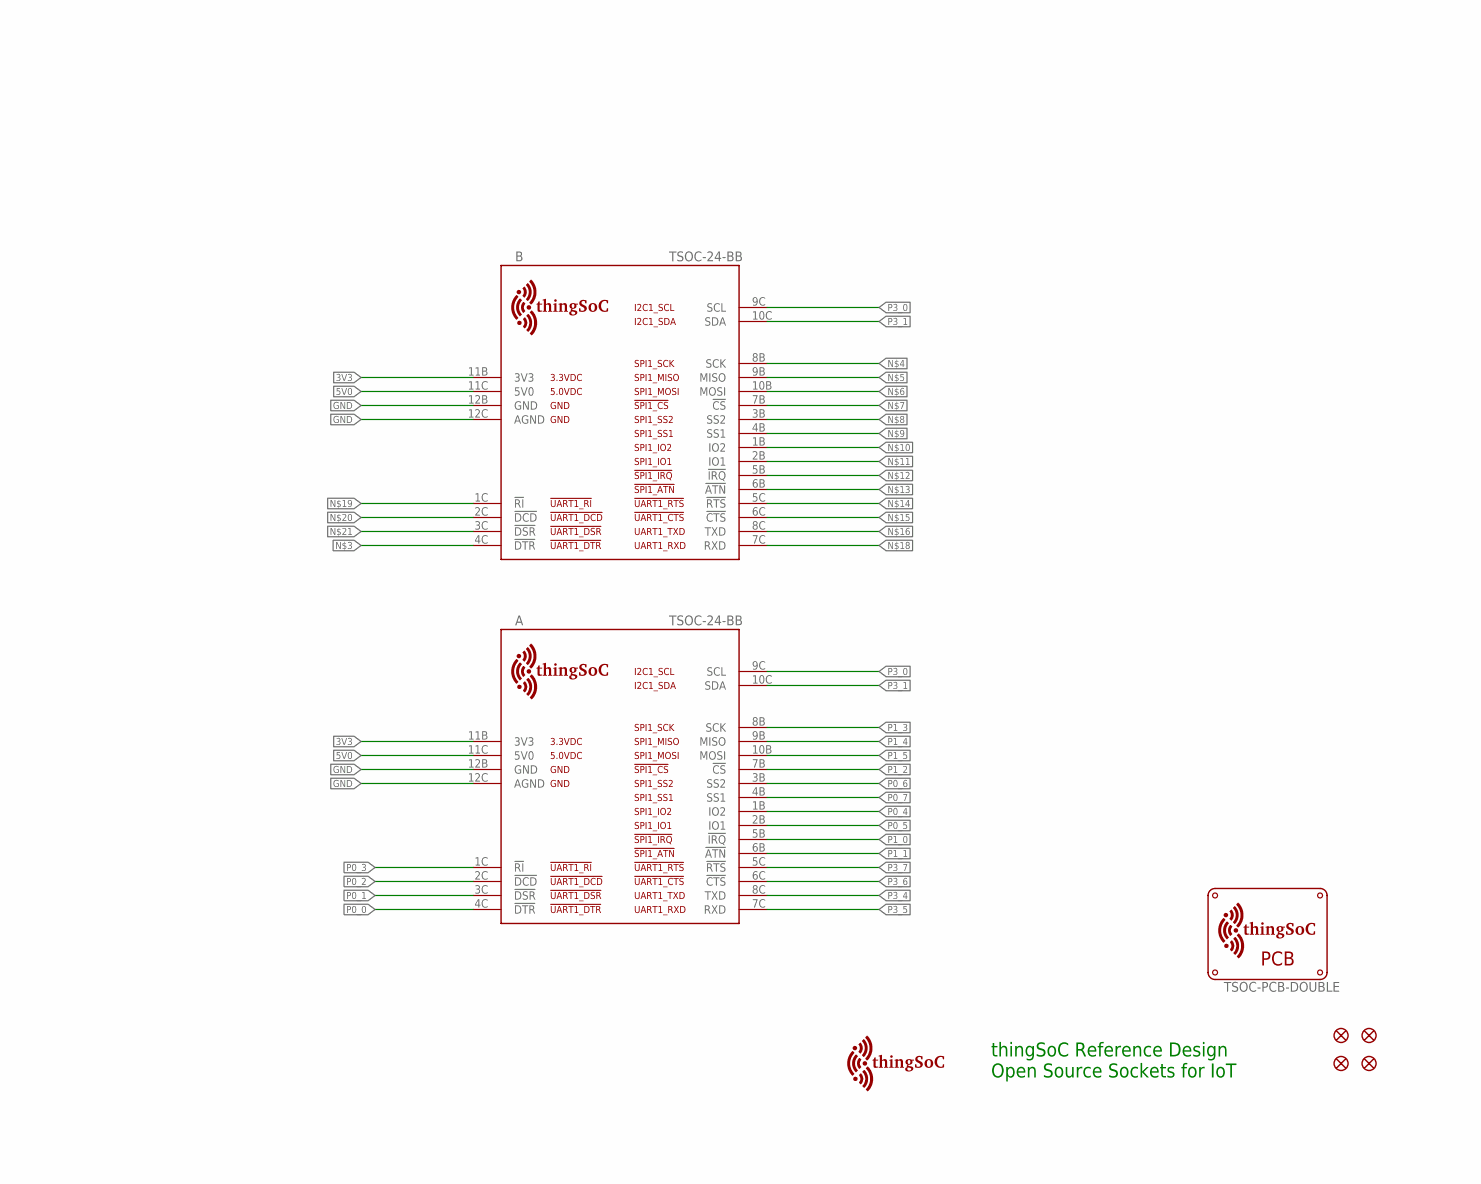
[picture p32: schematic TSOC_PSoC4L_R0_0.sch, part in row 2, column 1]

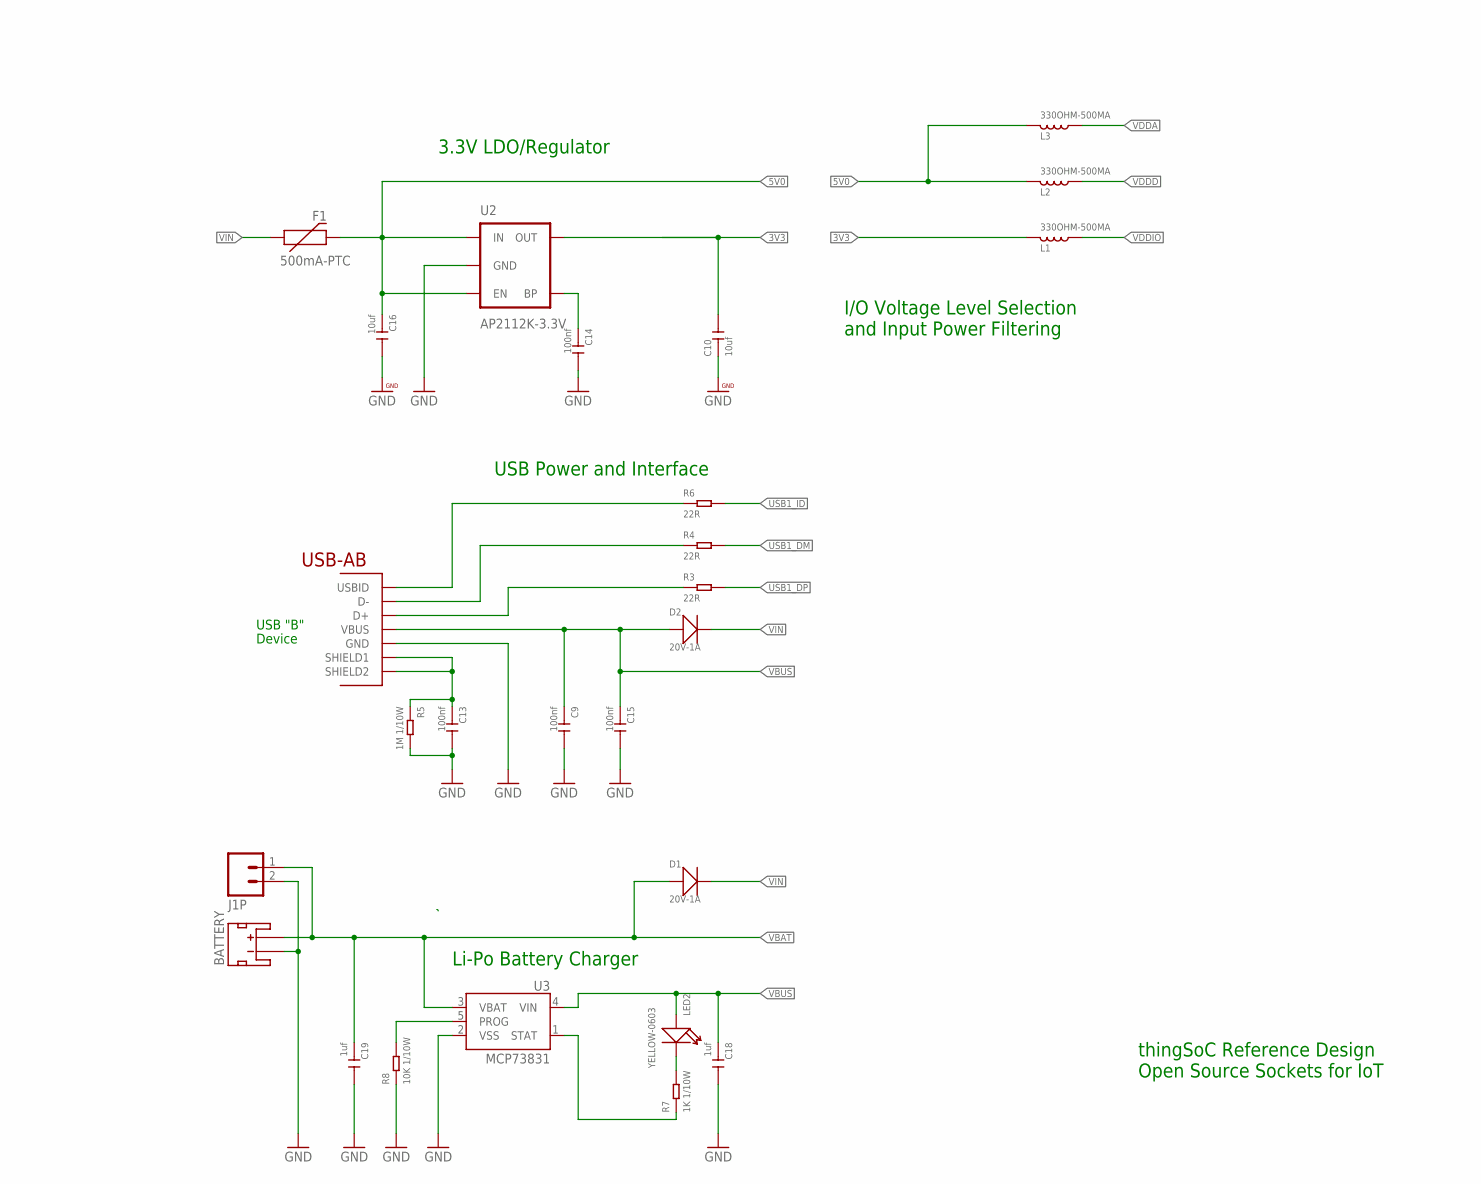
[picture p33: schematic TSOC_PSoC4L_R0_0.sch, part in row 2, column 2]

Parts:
A: TSOC-24-BB; TSOC-BB-S24
B: TSOC-24-BB; TSOC-BB-S24
BATTERY: JST_2MM_MALE; JST-2-SMD
C1, C4, C5, C7, C9, C13, C14, C15: 100nf; C0603
C2, C3, C6, C8, C12, C18, C19: 1uf; C0603
C10, C16: 10uf; C0603
C11, C17: 12pf; C0603
D1, D2: 20V-1A; SOD-123
F1: 500mA-PTC; PTC-1206
FID1, FID2, FID3, FID4: FIDUCIALUFIDUCIAL; MICRO-FIDUCIAL
J1P: M02-JST-2-PTH-NO_SILK; JST-2-PTH-NS
L1, L2, L3: 330OHM-500MA; L0603
LED1: GREEN-0603; LED-0603
LED2: YELLOW-0603; LED-0603
R1, R2, R8, R9: 10K 1/10W; R0603
R3, R4, R6: 22R; R0603
R5: 1M 1/10W; R0603
R7, R12: 1K 1/10W; R0603
U1: CY8C4247AZI-L433; TQFP-7X7-48
U2: AP2112K-3.3V; SOT23-5
U3: MCP73831; SOT23-5
U$1: TSOC-PCB-DOUBLE; TS0C-BB-BRD-DBL-DIM
U$100: TSOC-LOGO-SMALL; TSOC-LOGO-SML
U$101: TSOC-LOGO-LRG
USB: USB_AB; USB-AB-MICRO-SMD
Y1: 3.2768KHZ; X2-SMD-L2.0X1.2X0.55MM

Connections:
3V3: A.11B (3V3), B.11B (3V3), C10.2, L1.1, U2.5 (OUT)
5V0: A.11C (5V0), B.11C (5V0), C16.1, F1.2, L2.1, L3.1, U2.1 (IN), U2.3 (EN)
!XRES: C7.1, R9.1, U1.36 (!XRES)
BYPASS1: C14.1, U2.4 (BP)
CLED: LED2.-, R7.2
CSTAT: R7.1, U3.1 (STAT)
GND: A.12B (GND), A.12C (AGND), B.12B (GND), B.12C (AGND), BATTERY.1 (-), C1.2, C2.2, C3.2, C4.2, C5.2, C6.2, C7.2, C8.2, C9.2, C10.1, C11.2, C12.2, C13.2, C14.2, C15.2, C16.2, C17.2, C18.2, C19.2, J1P.2, LED1.-, R5.2, R8.1, U1.10 (VSSD), U1.38 (VSSD), U1.41 (VSSA), U2.2 (GND), U3.2 (VSS), USB.GND
unnamed: R8.2, U3.5 (PROG)
unnamed: LED1.+, R12.1
P0_0: A.4C (!DTR), U1.28 (P0_0)
P0_1: A.3C (!DSR), U1.29 (P0_1)
P0_2: A.2C (!DCD), U1.30 (P0_2)
P0_3: A.1C (!RI), U1.31 (P0_3)
P0_4: A.1B (IO2), C11.1, U1.32 (P0_4), Y1.1
P0_5: A.2B (IO1), C17.1, U1.33 (P0_5), Y1.2
P0_6: A.3B (SS2), U1.34 (P0_6)
P0_7: A.4B (SS1), U1.35 (P0_7)
P1_0: A.5B (!IRQ), U1.42 (P1_0)
P1_1: A.6B (!ATN), U1.43 (P1_1)
P1_2: A.7B (!CS), U1.44 (P1_2)
P1_3: A.8B (SCK), U1.45 (P1_3)
P1_4: A.9B (MISO), U1.46 (P1_4)
P1_5: A.10B (MOSI), U1.47 (P1_5)
P1_6: R12.2, U1.48 (P1_6)
P1_7: C12.1, U1.1 (P1_7/VREF)
P2_0: U1.2 (P2_0)
P2_1: U1.3 (P2_1)
P2_2: U1.4 (P2_2)
P2_3: U1.5 (P2_3)
P2_4: U1.6 (P2_4)
P2_5: U1.7 (P2_5)
P2_6: U1.8 (P2_6)
P2_7: U1.9 (P2_7)
P3_0: A.9C (SCL), B.9C (SCL), R2.1, U1.12 (P3_0)
P3_1: A.10C (SDA), B.10C (SDA), R1.1, U1.13 (P3_1)
P3_2: U1.14 (P3_2_SWD)
P3_3: U1.16 (P3_3_SWC)
P3_4: A.8C (TXD), U1.17 (P3_4)
P3_5: A.7C (RXD), U1.18 (P3_5)
P3_6: A.6C (!CTS), U1.19 (P3_6)
P3_7: A.5C (!RTS), U1.20 (P3_7)
P4_0: U1.22 (P4_0)
P7_0: U1.26 (P7_0)
P7_1: U1.27 (P7_1)
USB1_DM: R4.2, U1.24 (USBDN_P13_1)
USB1_DP: R3.2, U1.23 (USBDP_P13_0)
USB1_I: R6.1, USB.ID (USBID)
USB1_ID: R6.2
USB1_M: R4.1, USB.D-
USB1_P: R3.1, USB.D+
USB1_SHIELD: C13.1, R5.1, USB.SHIELD1, USB.SHIELD2
USB1_VBUS: U1.25 (VBUS)
VBAT: BATTERY.2 (+), C19.1, D1.+, J1P.1, U3.3 (VBAT)
VBUS: C9.1, C15.1, C18.1, D2.+, LED2.+, U3.4 (VIN), USB.VBUS
VCCD: C8.1, U1.37 (VCCD)
VDDA: C1.1, C2.1, L3.2, U1.40 (VDDA)
VDDD: C5.1, C6.1, L2.2, R9.2, U1.39 (VDDD)
VDDIO: C3.1, C4.1, L1.2, R1.2, R2.2, U1.21 (VDDIO)
VIN: D1.-, D2.-, F1.1

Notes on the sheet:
Internal/Core Bypass
Digital Bypass
VDDIO Bypass
SAR Bypass
USB "B"
Device
3.3V LDO/Regulator
Reset Pullup
Heartbeat LED
Analog Bypass
Li-Po Battery Charger
USB Power and Interface
I/O Voltage Level Selection and Input Power Filtering
I2C Pullups
32,768 KHz Crystal (RTC Clock)
thingSoC Reference Design Open Source Sockets for IoT

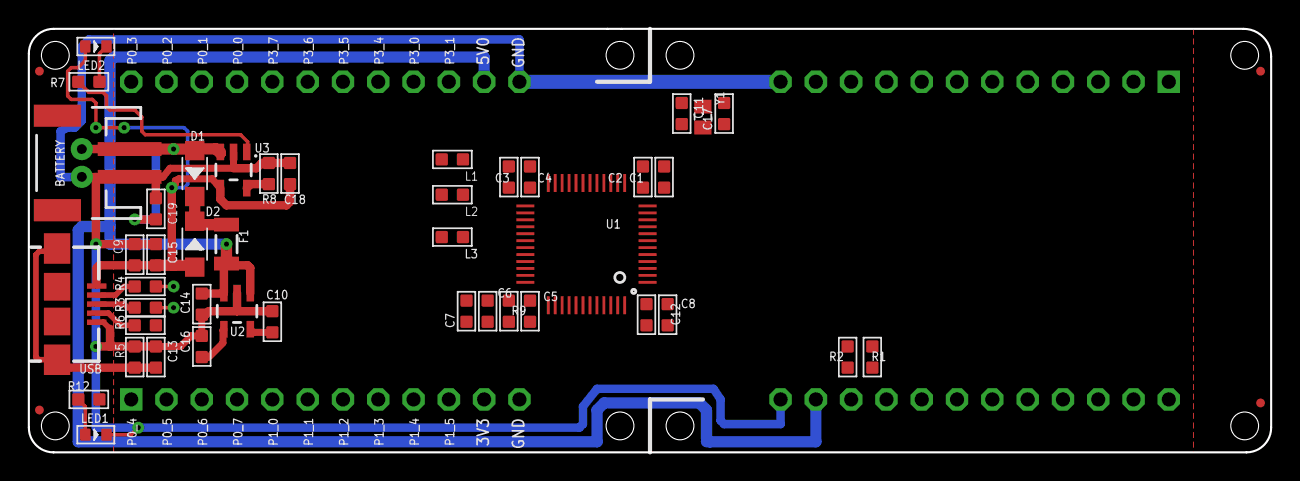
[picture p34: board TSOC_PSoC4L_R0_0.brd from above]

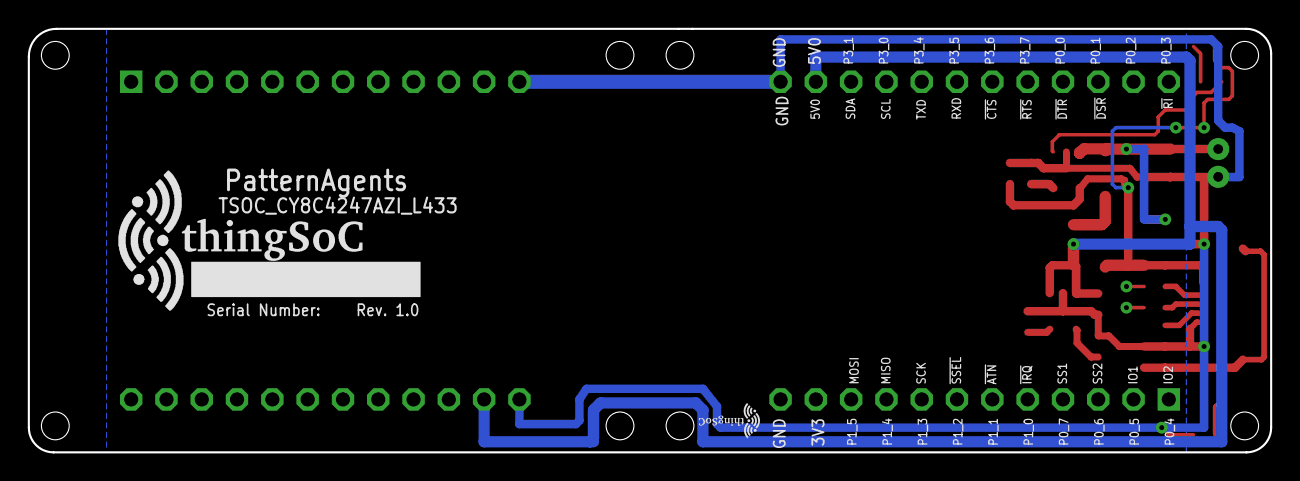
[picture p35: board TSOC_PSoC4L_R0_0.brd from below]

Board: 2 copper layers, 89.4 x 30.5 mm, 53 parts (3 on the bottom side), 44 nets.

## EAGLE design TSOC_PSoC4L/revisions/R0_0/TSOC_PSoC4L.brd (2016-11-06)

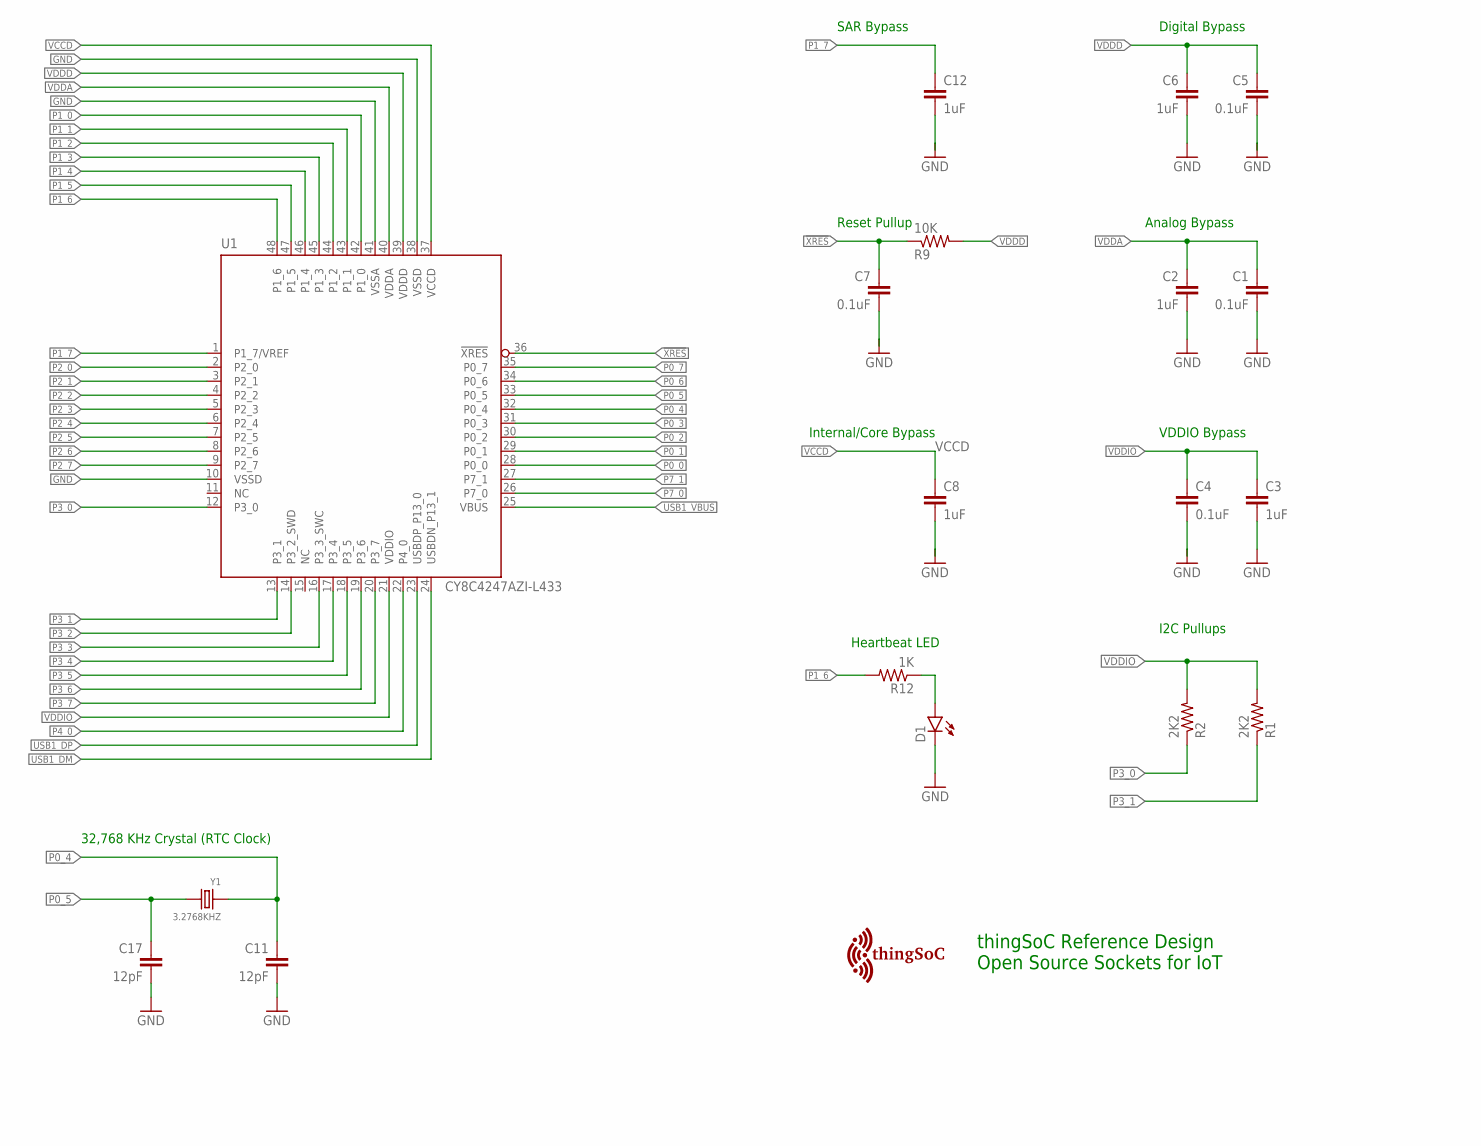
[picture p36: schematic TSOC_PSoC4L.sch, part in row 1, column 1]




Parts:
BATTERY: JST_2MM_MALE; JST-2-SMD
C1, C4, C5, C7: 0.1uF; 0603-CAP
C2, C3, C6, C8, C12, C18: 1uF; 0603-CAP
C9: 0.1uF; 0402-CAP
C11, C17: 12pF; 0603-CAP
C13, C14: 470nF; 0402-CAP
C15, C16: 10µF; 0805-NO
CHRG: RED; LED-0603
D1: LED0603; LED-0603
D2, D3: 20V-1A; SOD-123
ESD1: SP1001-02JTG; SC70-3
F1: 500mA-PTC; PTC-1206
FID1, FID2, FID3, FID4: FIDUCIALUFIDUCIAL; MICRO-FIDUCIAL
J1: M08X2; 2X8
J1P: M02-JST-2-PTH-NO_SILK; JST-2-PTH-NS
L1, L2, L3: 330OHM-500MA; L0603
R1, R2: 2K2; 0603-RES
R5: 1M; 0402-RES
R7: 1K; 0402-RES
R8: 10K; 0402-RES
R9: 10K; 0603-RES
R12: 1K; 0603-RES
SJ1: JMP-3-NC
TSOC: TSOC-24-BB; TSOC-BB-S24
U1: CY8C4247AZI-L433; TQFP-7X7-48
U2: MIC5219 3.3V; SOT23-5
U3: MCP73831; SOT23-5
U$1: TSOC-PCB-SINGLE; TSOC-BB-BRD-DIM
U$100: TSOC-LOGO-SMALL; TSOC-LOGO-SML
U$101: TSOC-LOGO-LRG
USB: USB_AB; USB-AB-MICRO-SMD
Y1: 3.2768KHZ; X2-SMD-L2.0X1.2X0.55MM

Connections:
3V3: C15.1, SJ1.1, TSOC.11B (3V3), U2.5 (OUT)
5V0: C16.1, D2.-, D3.-, L2.1, L3.1, SJ1.3, TSOC.11C (5V0), U2.1 (IN), U2.3 (EN)
!XRES: C7.1, J1.5, R9.1, U1.36 (!XRES)
BYPASS1: C14.1, U2.4 (BP)
CLED: CHRG.C, R7.2
CSTAT: R7.1, U3.1 (STAT)
GND: BATTERY.1 (-), C1.2, C2.2, C3.2, C4.2, C5.2, C6.2, C7.2, C8.2, C9.2, C11.2, C12.2, C13.2, C14.2, C15.2, C16.2, C17.2, C18.2, D1.C, ESD1.3 (A), J1.15, J1.16, J1P.2, R5.2, R8.1, TSOC.12B (GND), TSOC.12C (AGND), U1.10 (VSSD), U1.38 (VSSD), U1.41 (VSSA), U2.2 (GND), U3.2 (VSS), USB.GND
unnamed: R8.2, U3.5 (PROG)
unnamed: D1.A, R12.1
P0_0: TSOC.4C (!DTR), U1.28 (P0_0)
P0_1: TSOC.3C (!DSR), U1.29 (P0_1)
P0_2: TSOC.2C (!DCD), U1.30 (P0_2)
P0_3: TSOC.1C (!RI), U1.31 (P0_3)
P0_4: C11.1, TSOC.1B (IO2), U1.32 (P0_4), Y1.1
P0_5: C17.1, TSOC.2B (IO1), U1.33 (P0_5), Y1.2
P0_6: TSOC.3B (SS2), U1.34 (P0_6)
P0_7: TSOC.4B (SS1), U1.35 (P0_7)
P1_0: TSOC.5B (!IRQ), U1.42 (P1_0)
P1_1: TSOC.6B (!ATN), U1.43 (P1_1)
P1_2: TSOC.7B (!CS), U1.44 (P1_2)
P1_3: TSOC.8B (SCK), U1.45 (P1_3)
P1_4: TSOC.9B (MISO), U1.46 (P1_4)
P1_5: TSOC.10B (MOSI), U1.47 (P1_5)
P1_6: R12.2, U1.48 (P1_6)
P1_7: C12.1, U1.1 (P1_7/VREF)
P2_0: J1.1, U1.2 (P2_0)
P2_1: U1.3 (P2_1)
P2_2: J1.2, U1.4 (P2_2)
P2_3: J1.4, U1.5 (P2_3)
P2_4: J1.6, U1.6 (P2_4)
P2_5: U1.7 (P2_5)
P2_6: U1.8 (P2_6)
P2_7: J1.14, U1.9 (P2_7)
P3_0: J1.3, R2.1, TSOC.9C (SCL), U1.12 (P3_0)
P3_1: J1.13, R1.1, TSOC.10C (SDA), U1.13 (P3_1)
P3_2: J1.9, U1.14 (P3_2_SWD)
P3_3: J1.7, U1.16 (P3_3_SWC)
P3_4: TSOC.8C (TXD), U1.17 (P3_4)
P3_5: TSOC.7C (RXD), U1.18 (P3_5)
P3_6: TSOC.6C (!CTS), U1.19 (P3_6)
P3_7: TSOC.5C (!RTS), U1.20 (P3_7)
P4_0: J1.10, U1.22 (P4_0)
P4_1: J1.8
P7_0: U1.26 (P7_0)
P7_1: U1.27 (P7_1)
SJ1: L1.1, SJ1.2
USB1_DM: ESD1.2 (C2), U1.24 (USBDN_P13_1), USB.D-
USB1_DP: ESD1.1 (C1), U1.23 (USBDP_P13_0), USB.D+
USB1_ID: USB.ID (USBID)
USB1_SHIELD: C13.1, R5.1, USB.SHIELD1, USB.SHIELD2
USB1_VBUS: C18.1, CHRG.A, D2.+, F1.2, U1.25 (VBUS), U3.4 (VIN)
VBAT: BATTERY.2 (+), D3.+, J1P.1, U3.3 (VBAT)
VBUS1: C9.1, F1.1, USB.VBUS
VCC: J1.11, J1.12
VCCD: C8.1, U1.37 (VCCD)
VDDA: C1.1, C2.1, L3.2, U1.40 (VDDA)
VDDD: C5.1, C6.1, L2.2, R9.2, U1.39 (VDDD)
VDDIO: C3.1, C4.1, L1.2, R1.2, R2.2, U1.21 (VDDIO)

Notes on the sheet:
Internal/Core Bypass
Digital Bypass
I2C-SDA
I2C-SDL
!RESET
SWDCLK
SWDIO
POWER
GROUND
!DEBUG
!RTS
!CTS
!DTR
TXD
RXD
VDDIO Bypass
SAR Bypass
USB "B"
Device
3.3V LDO/Regulator
Reset Pullup
Heartbeat LED
Analog Bypass
Li-Po Battery Charger
USB Power and Interface
I/O Voltage Level Selection and Input Power Filtering
I2C Pullups
32,768 KHz Crystal (RTC Clock)
thingSoC Reference Design Open Source Sockets for IoT

Board: 2 copper layers, 50 parts (3 on the bottom side), 51 nets, no tracks yet.

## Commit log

2016-11-06 update PSoC4L
    [TSOC_PSoC4L.brd, TSOC_PSoC4L.sch, TSOC_PSoC4L.skp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]
2016-11-18 update hardware files
    [TSOC_PSoC4L_BOM.csv]
2016-12-02 update to Rev1.2
    [TSOC_PSoC4L.brd, TSOC_PSoC4L.sch, TSOC_PSoC4L_BOM.csv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]
2017-01-14 update documetation
    [TSOC_PSoC4l_pinout.ods]

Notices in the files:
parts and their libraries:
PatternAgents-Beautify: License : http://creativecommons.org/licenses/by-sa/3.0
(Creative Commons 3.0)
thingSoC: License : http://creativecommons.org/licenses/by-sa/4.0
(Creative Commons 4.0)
